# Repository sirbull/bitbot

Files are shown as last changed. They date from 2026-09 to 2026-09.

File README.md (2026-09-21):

# BitBot

**A tiny robot face with a voice, a camera, and a big personality.**

BitBot is a DIY AI companion built around the Seeed Studio XIAO ESP32-S3 Sense. It listens for a wake phrase or a button press, shows expressions and captions on a 240 × 240 screen, and can take a photo when asked what it sees. Its voice pipeline sends replies to a small speaker. The ESP32-S3 handles the hardware and local wake detection; conversations run through XiaoZhi over Wi-Fi.

> **Prototype status:** The display, face, camera, setup portal, wake phrases, and XiaoZhi conversation path have been implemented and tested in stages. Audible output from the physical speaker and the battery power system still need final bench verification. Battery life has not been measured.

## Meet the hardware

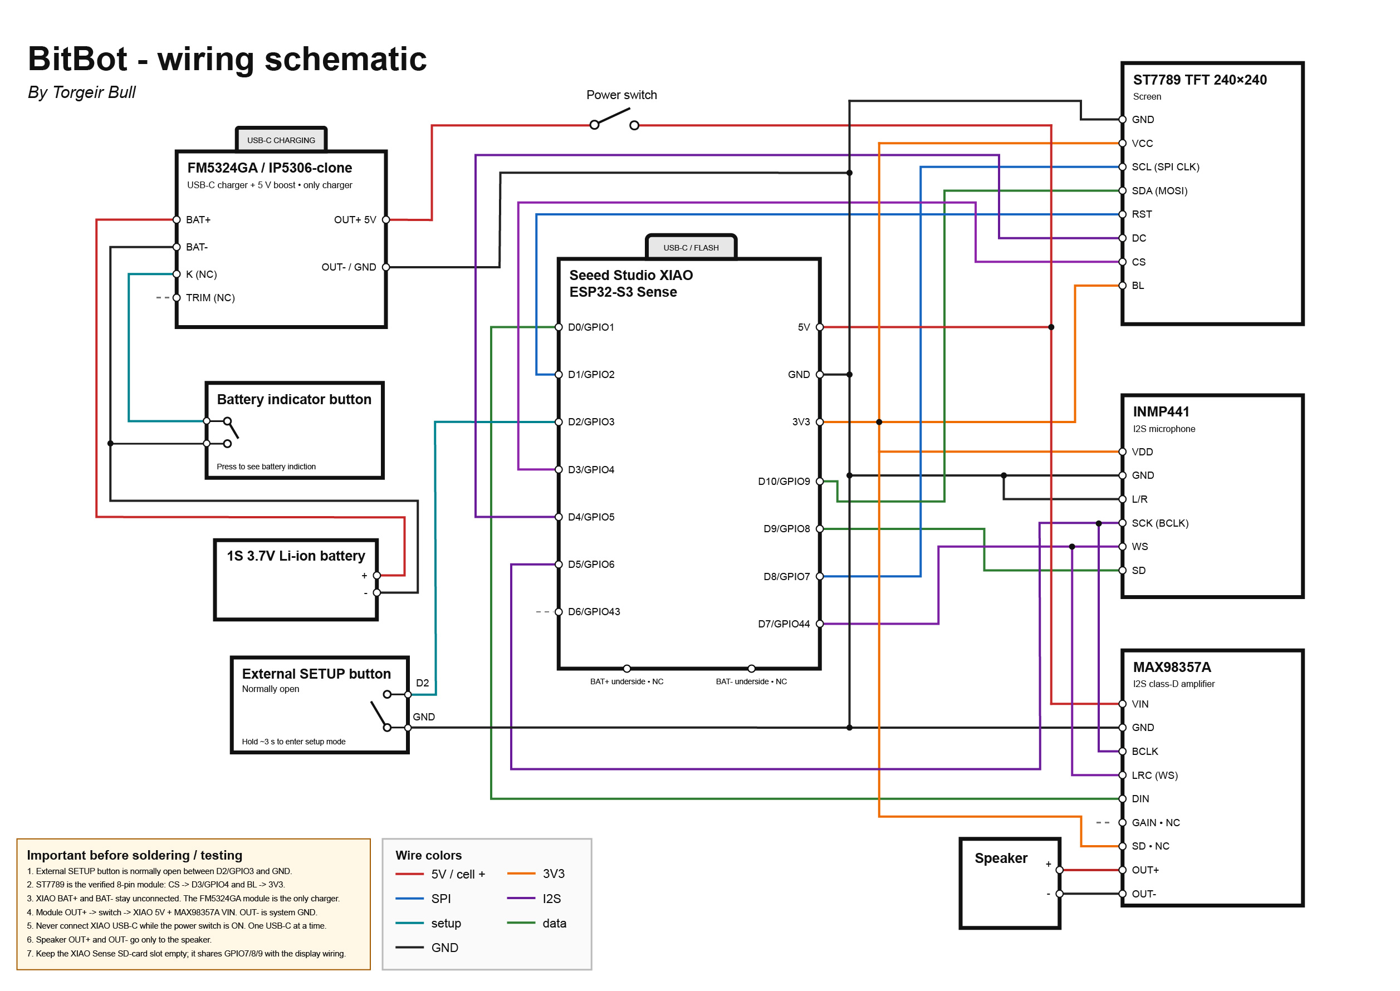
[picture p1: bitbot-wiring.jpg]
BitBot circuit wiring schematic


[Open the full-size circuit diagram](bitbot-wiring.jpg) · [Read the latest wiring notes](docs/wiring.md)

The image shows how the controller, screen, microphone, amplifier, speaker, controls, and power module fit together. It is a **prototype schematic**, so check the wiring notes before building: for example, the current notes connect the amplifier's `SD` pin to 3V3, while the image labels it `NC`.

### Parts at a glance

| Part | What it does |
| --- | --- |
| **Seeed Studio XIAO ESP32-S3 Sense** | Runs BitBot; includes Wi-Fi and the camera. |
| **1.54-inch ST7789 display, 240 × 240, 8-pin** | Shows the animated face, setup instructions, photos, and captions. |
| **INMP441 I²S microphone** | Captures speech. |
| **MAX98357A I²S amplifier + small speaker** | Plays BitBot's replies. |
| **Momentary button** (optional) | Starts a conversation or reopens setup; the onboard BOOT button also works. |
| **1S Li-ion cell, charger/5 V boost module, and latching switch** | Planned portable power; validate the cell and charging current before connecting them. |

See the [full component list](docs/components.md) for module details and the [hardware notes](docs/hardware.md) for electrical constraints. The Sense board's SD card slot stays empty because its pins are shared with the display.

## How BitBot works

1. **Set it up.** On first boot, BitBot opens its own Wi-Fi hotspot. Join it and open `http://192.168.4.1` to save a 2.4 GHz network and preferences. The screen shows setup information.
2. **Get its attention.** Press BOOT or the optional external button, or say **“hey robot”** or **“hey bit robot”**. Wake detection runs on the ESP32-S3. A custom “hey BitBot” wake model is future work.
3. **Have a conversation.** The microphone audio travels to XiaoZhi over Wi-Fi. BitBot receives the reply as text and audio, shows captions and a matching expression, and sends the audio to its speaker.
4. **Ask what it sees.** When the assistant requests a photo, BitBot captures one with the Sense camera, previews it on the display, and sends it to the vision service. The camera is not used continuously for conversation.

The face has twelve expressions, blinking eyes, and a dimmed idle view. Press the button again to interrupt or end a reply. [Learn more about the architecture](docs/architecture.md).

## What works today

| Area | Status |
| --- | --- |
| Screen, expressions, and captions | Implemented; ST7789 wiring verified on hardware. |
| Wi-Fi setup | Local English portal, saved network profiles, and a desktop simulator. |
| Voice and vision | XiaoZhi pairing and conversation flow, local wake phrases, and on-demand camera capture are implemented. Physical speaker output is still being diagnosed. |
| Portable power | Circuit planned; charging current, boost behavior, and battery runtime still need measurement. |

BitBot is a hands-on prototype, not a finished product. The [next-steps checklist](docs/next-steps.md) tracks the remaining physical tests.

## Try the setup portal on your computer

The simulator lets you explore BitBot's settings without hardware or an AI account. Install **Node.js 22 or later**, then run:

```sh
npm ci
npm run dev
```

Open **http://127.0.0.1:4173**. The simulator stores preferences in ignored `.local/simulator.json`; use dummy credentials. Its Wi-Fi checks are simulated and it makes no AI calls. To exercise a failed network test, enter `wrong-password`; other valid demo passwords simulate success.

## Build and flash the device

The firmware targets **ESP-IDF 6.0.2** and the original **XIAO ESP32-S3 Sense**. In an ESP-IDF shell:

```sh
cd firmware
idf.py set-target esp32s3
idf.py build
idf.py -p COM5 flash monitor
```

Replace `COM5` with your board's serial port. If you do not have ESP-IDF locally, see the [CI artifact flashing guide](docs/flashing.md). On first boot, join the `BitBot-XXXX` hotspot and open **http://192.168.4.1**. Holding BOOT for three seconds after startup reopens setup without erasing saved settings.

**Start on USB power with the battery module disconnected.** Read the [wiring guide](docs/wiring.md) before connecting external power. The XIAO's USB-C port and the boost module's switched 5 V output must not power the board at the same time.

## For contributors

Run the portal build and automated checks with:

```sh
npm ci
npx playwright install chromium
npm run check
```

The build generates compressed portal assets in `firmware/main/generated/`; commit those assets when changing `web/` or the settings schema. GitHub Actions also compiles the ESP32-S3 firmware.

| Path | Contents |
| --- | --- |
| [`firmware/`](firmware/) | ESP-IDF firmware for setup, face, audio, camera, and network. |
| [`web/`](web/) | Local setup portal shared by the device and simulator. |
| [`hwtest/`](hwtest/) | Separate hardware bring-up firmware. |
| [`docs/`](docs/) | Wiring, components, architecture, flashing, and progress notes. |
| [`BitBot_PROJECT_SPEC.md`](BitBot_PROJECT_SPEC.md) | Original project vision and requirements. |

This developer firmware stores credentials in NVS without flash encryption. Use test credentials while developing, and do not commit passwords or API keys.

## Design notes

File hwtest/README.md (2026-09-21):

# Maskinvaretest

Eget lite ESP-IDF-program som viser på skjermen hvilke deler som svarer.
Pinner som i [docs/wiring.md](../docs/wiring.md). Bruker samme partisjonstabell
som hovedfirmwaren, så lagrede Wi-Fi-innstillinger blir liggende.

```sh
. ~/esp/esp-idf-v6.0.2/export.sh
cd hwtest
idf.py -p /dev/cu.usbmodem11201 flash monitor
```

Tilbake til vanlig firmware: `cd ../firmware && idf.py -p ... flash`.

**D6/GPIO43 takler ikke en rask I2S-klokke** på dette kortet. BCLK flyttet
til D5/GPIO6 (var ledig siden batterisensing er fjernet). D6 fungerer fint
som sakte digital I/O (testet: 1 Hz toggling, ren 0/3,3V) — ledig pinne til
noe som en reset-linje, bare ikke en ny rask klokke.

| Linje | Grønn betyr | Rød / annet |
| --- | --- | --- |
| CPU / PSRAM | 8 MB PSRAM funnet | 0 MB: feil kort eller sdkconfig |
| MIC | INMP441 sender data; stolpen følger lyd | NO SIGNAL: SD-linjen (GPIO8) står fast. Sjekk VDD, SCK, WS, SD og L/R→GND. `MIC R` = L/R står høy |
| SPEAKER | `ok` og et lite tall: DMA-en ble aldri tom | BOOT stepper tonen: av, 2 %, 10 %, 40 %, 40 % uten mikrofon. Rød `GAP<ms>` betyr at skriveren ble sultet, og det hullet *er* skrapet |
| CAMERA | Sensornavn og bilder/s, bilde nederst | NOT FOUND: kamera-kabel. Trykk RESET etter tilkobling |

Trykker du BOOT innen 3 sekunder etter reset, starter i stedet en ren lyddiagnose:
skjerm, kamera, batteri og mikrofon blir aldri initialisert, og programmet veksler
mellom fire sekunder digital stillhet og fire sekunder 440 Hz. Støy under stillheten
kan ikke komme fra samplene. Videre BOOT-trykk stepper gjennom seks I2S-formater.

Uten kamera viser nederste halvdel tre felt som skal være rød, grønn, blå.
Kalibrering (invertering, radforskyvning) står øverst i
[main/main.cpp](main/main.cpp).

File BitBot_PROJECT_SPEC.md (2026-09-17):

# BitBot -- Project Specification for Codex

> **Purpose of this document:** This file is the persistent project
> brief for Codex and other development tools working on BitBot. Read it
> before making architectural, firmware, hardware, GPIO, display, audio,
> camera, networking, AI-provider, or power-management changes.

## 1. Project vision

BitBot is a small, portable, battery-powered AI assistant built around
the **Seeed Studio XIAO ESP32-S3 Sense**.

It is not a motorized robot. It has no wheels, servos, or locomotion.
The goal is to create a compact character-like AI device with:

-   voice interaction;
-   a reactive animated face;
-   a small color display;
-   a camera that is activated only when useful;
-   cloud-based AI over Wi-Fi;
-   Norwegian and English conversation;
-   spoken responses and simultaneous on-screen captions;
-   local device functions such as time, battery status, and camera
    preview;
-   aggressive but practical power management for portable battery
    operation.

The device should feel like a small character rather than merely a voice
terminal.

Two open-source projects should be investigated as important references:

-   `idevloop/AI_Pin-Wearable_Voice_Assistant_XIAO_ESP32S3_Sense`
-   `78/xiaozhi-esp32`

The first is especially relevant because it targets XIAO ESP32-S3 Sense
with camera and voice-assistant functionality. XiaoZhi is relevant as
the broader AI-assistant framework. BitBot may combine concepts or code
from both where licenses and architecture permit.

Do not assume that either project should simply be copied unchanged.
First determine which should be the primary technical foundation.

------------------------------------------------------------------------

## 2. Core hardware

### Main controller

**Seeed Studio XIAO ESP32-S3 Sense**

Requirements:

-   ESP32-S3 is the main MCU.
-   The Sense camera expansion board/camera must remain supported.
-   PSRAM should be used where appropriate.
-   Wi-Fi is required.
-   USB should remain usable for development/flashing/debugging.
-   GPIO assignments must be verified against official Seeed
    documentation and the actual camera pin usage.

### Camera

Use the camera supplied with the **XIAO ESP32-S3 Sense**.

The camera is **not intended to run continuously**.

Primary camera use cases:

1.  User asks a visual question such as:
    -   "What do you see?"
    -   "Hva ser du?"
    -   "What is this?"
    -   "Hva er dette?"
    -   "Read this."
    -   "Les dette."
2.  User requests a camera preview:
    -   "Show me what you see."
    -   "Vis meg hva du ser."
3.  While BitBot is awake, lightweight local person/face-position
    detection may optionally be used to make the on-screen eyes look
    toward the user.

The implementation must distinguish between:

-   local camera preview;
-   lightweight local visual tracking;
-   cloud vision inference.

Do not send camera images to a cloud service unless the requested
function actually requires cloud vision.

Camera operation should be designed with privacy, memory use, latency,
and battery consumption in mind.

### Display

**1.54-inch ST7789 TFT LCD**

Known characteristics:

-   240 × 240 pixels
-   SPI
-   7-pin style module
-   module pins:
    -   GND
    -   VCC
    -   SCL / SCK
    -   SDA / MOSI
    -   RES / RST
    -   DC
    -   BLK / BL

Owner-confirmed on 2026-09-10: with the pins at the top, the left-to-right
order is **GND, VCC, SCK, SDA, RES, DC, BLK**. This module has **no CS pin**.
Use ST7789 SPI support with chip-select disabled and exclusive bus ownership.
Do not use an SD card on that SPI bus. See `docs/hardware.md` for the current
signal allocation and unverified supply/backlight requirements.

Important:

-   This is **not** the SSD1306 OLED used by some reference projects.
-   BitBot must use the ST7789 as its main UI.
-   Verify the exact module electrical requirements before finalizing
    wiring.
-   Do not infer GPIO assignments from unrelated ESP32 boards.

### Microphone

**INMP441 digital MEMS microphone**

Interface:

-   I2S
-   pins typically include:
    -   VDD
    -   GND
    -   SCK / BCLK
    -   WS / LRCLK
    -   SD
    -   L/R

The microphone is used for:

-   local wake-word detection;
-   capturing user speech after wake-up;
-   sending speech/audio to the selected speech-recognition system where
    required.

Verify the actual module pinout before wiring.

### Audio amplifier

**MAX98357A I2S Class-D amplifier module**

Used for speech/audio output.

Expected signals include:

-   power;
-   GND;
-   I2S BCLK;
-   I2S LRCLK/LRC;
-   I2S DIN;
-   speaker outputs.

The amplifier may be disabled or power-managed when BitBot is inactive
if the hardware permits it.

### Speaker

Small rectangular speaker, approximately:

-   15 × 11 × 3.5--4 mm.

Verify actual impedance and power rating before finalizing amplifier
configuration.

Important: the MAX98357A speaker output is differential/bridge output.
Do not assume either speaker terminal connects to system ground.

### Battery

Current planned cell:

**10440 Li-ion** - nominal voltage: 3.7 V - advertised capacity:
approximately 350 mAh

The device must be portable and battery powered.

Battery runtime is an important design constraint. Measure real-world
current consumption once the prototype works.

### Charging / power module

Identified 2026-09-17. The purchased module is a **Type-C USB boost
converter, 5 V 2 A step-up with 1S Li-ion charging/protection and a
4-LED gauge**, built on an IC marked **FM5324GA**, a clone of the
**IP5306**.

Pads:

-   USB-C input (BitBot's charging port);
-   battery positive / battery negative;
-   5 V output positive / output negative;
-   external key pad `K`, marked as not connectable on this board;
-   charge-voltage trim point.

Topology is boost, not load-sharing: the 5 V rail is generated from the
cell while the cell charges from USB-C, so charging while BitBot is
switched off works. `BAT-` and `OUT-` are the same node, giving the
system one common ground.

The 5 V output becomes BitBot's supply rail: through the latching switch
to the XIAO's 5V pad and to the MAX98357A's VIN. **The module is the
only charger.** The XIAO's own `BAT+`/`BAT-` pads stay unconnected, and
the XIAO's USB-C must not be plugged in while the switch is on.

Two module characteristics remain to be measured on the bench, and both
can change component choices:

-   **actual charge current into a cell.** The family's default is close
    to 2 A, which is roughly 6C for a 350 mAh 10440 and unsafe. A larger
    cell or a current-limited charger may be required.
-   **boost auto-shutdown at low load.** The family cuts its output below
    roughly 45--100 mA. With no usable key pad, this may rule out deep
    sleep.

See `docs/hardware.md` for the test procedure and `docs/wiring.md` for
the wiring.

### Main power switch

A self-locking ON/OFF pushbutton has been purchased.

Approximate listing specification:

-   12 × 8 mm
-   latching/self-locking
-   advertised up to 30 V / 1 A

Only one switch will be used.

Prefer an arrangement that allows the battery to charge while BitBot is
switched off, if supported safely by the charging module.

### Battery measurement

BitBot should measure its own battery voltage.

Initial planned implementation:

-   2 × 100 kΩ, 1% resistors;
-   voltage divider from raw battery voltage to a suitable ESP32-S3 ADC
    input;
-   optional \~100 nF capacitor from ADC measurement node to GND for
    filtering.

Concept:

``` text
BAT+
 |
100k
 |
 +---- ADC
 |
100k
 |
GND
```

Software should compensate for the divider ratio and convert voltage to
an approximate Li-ion state of charge.

Do **not** use a simple linear 3.0--4.2 V percentage mapping if a more
realistic Li-ion lookup/curve can be implemented.

The result remains an estimate; load-dependent voltage sag should be
considered.

------------------------------------------------------------------------

## 3. No motors

BitBot does **not** require:

-   DC motors;
-   motor drivers;
-   wheels;
-   servos;
-   locomotion.

Do not reserve GPIO pins or power budget for motors unless the project
requirements are explicitly changed later.

------------------------------------------------------------------------

## 4. Wake word

BitBot should support a local wake phrase, initially:

**"Hey BitBot"**

Desired behavior:

``` text
low-power/idle
      |
"Hey BitBot"
      |
      v
   awake
      |
   listening
      |
 speech/command
```

Wake-word recognition should preferably happen locally on the ESP32-S3
rather than continuously streaming microphone audio to the cloud.

Goals:

-   lower network usage;
-   improved privacy;
-   lower cloud cost;
-   reduced unnecessary processing;
-   reasonable battery consumption.

Investigate practical ESP32-S3 wake-word solutions compatible with the
selected framework and with Norwegian/English usage.

Do not assume that deep sleep is compatible with microphone wake-word
recognition. Determine the lowest practical power state in which the
selected wake-word engine can function.

If true wake-on-voice from a very low-power state requires additional
hardware, document that clearly.

------------------------------------------------------------------------

## 5. Interaction state machine

BitBot should have explicit behavioral states rather than scattered UI
flags.

Initial conceptual states:

``` text
BOOTING
IDLE
SLEEPING / LOW_POWER
WAKING
LISTENING
PROCESSING
THINKING
SPEAKING
CAMERA_PREVIEW
VISION_PROCESSING
OFFLINE
ERROR
LOW_BATTERY
```

State transitions should drive:

-   face animation;
-   display content;
-   camera state;
-   microphone state;
-   amplifier/audio state;
-   Wi-Fi/network activity where practical;
-   backlight behavior;
-   power-management decisions.

Keep the state machine modular and understandable.

------------------------------------------------------------------------

## 6. Reactive face and character UI

The 240 × 240 ST7789 display should normally show a **BitBot face**.

The face is a major feature of the project.

It must be easy to redesign later without rewriting the AI/audio/camera
subsystems.

Prefer a dedicated abstraction such as:

``` cpp
face.setState(FaceState::Listening);
face.setGaze(x, y);
face.setSpeechLevel(level);
face.setCaption(text);
```

The exact API may differ, but UI/face rendering should be decoupled from
AI logic.

### Desired visual behavior

Possible expressions/states include:

-   sleeping;
-   waking;
-   neutral/idle;
-   listening;
-   thinking;
-   speaking;
-   happy;
-   amused;
-   uncertain;
-   confused;
-   surprised;
-   error;
-   low battery;
-   no Wi-Fi.

The face should not necessarily be implemented as a collection of static
full-screen bitmaps.

Where feasible, draw/animate individual components such as:

-   eyes;
-   pupils;
-   eyelids;
-   mouth;
-   eyebrows or equivalent expressive elements.

This makes redesign and animation easier.

### Idle animation

The face may:

-   blink occasionally;
-   make subtle eye movements;
-   react when woken;
-   transition smoothly between important states.

Avoid excessive animation that wastes CPU/battery without improving the
experience.

------------------------------------------------------------------------

## 7. Gaze / user position

When BitBot is awake and camera use is appropriate, the eyes should
optionally react to where a person appears in the camera image.

Example:

-   person appears left of image center -\> pupils move left;
-   person appears right -\> pupils move right;
-   person is higher/lower -\> gaze can shift vertically.

This should preferably use lightweight **local** detection rather than
repeatedly uploading images to a cloud vision model.

Important conflict to handle:

BitBot's camera should not run continuously while the device is asleep.
Therefore gaze tracking is expected primarily while BitBot is in an
awake/interactive state.

A possible policy is:

1.  BitBot is idle in a low-power state.
2.  "Hey BitBot" wakes it.
3.  During the active session, camera-based lightweight tracking may run
    when useful.
4.  After an inactivity timeout, tracking and camera are disabled.
5.  BitBot returns to low-power mode.

Investigate whether continuous camera operation during the entire awake
session is necessary. Prefer intermittent or low-frame-rate tracking if
it substantially improves battery life.

------------------------------------------------------------------------

## 8. Camera preview

The user should be able to say something equivalent to:

**"Vis meg hva du ser."**\
**"Show me what you see."**

BitBot should then show the camera image on the ST7789.

This is a local preview operation and should not require cloud AI.

Requirements:

-   camera initializes/activates;
-   frames are converted/scaled as required for 240 × 240;
-   image is shown on the ST7789;
-   provide a way to exit preview;
-   automatically exit after a sensible timeout if appropriate;
-   release/disable camera resources afterwards where practical.

Memory bandwidth, PSRAM, display SPI speed, frame format, and frame rate
should be considered.

A smooth 30 FPS video feed is not required. Responsiveness and
reasonable battery use are more important.

------------------------------------------------------------------------

## 9. Vision AI

When the user asks a question that genuinely requires visual
understanding, BitBot may:

1.  activate the camera;
2.  capture an appropriate still image;
3.  optionally resize/compress it;
4.  send it over Wi-Fi to a vision-capable AI service;
5.  receive the answer;
6.  speak and display the answer;
7.  deactivate the camera when no longer needed.

Examples:

-   "Hva ser du?"
-   "What is in front of you?"
-   "Hva slags plante er dette?"
-   "Les teksten på denne boksen."
-   "What color is this object?"

Cloud vision should be invoked by intent/tool selection, not
continuously.

------------------------------------------------------------------------

## 10. Languages

BitBot must support:

-   **Norwegian**
-   **English**

Norwegian is a first-class requirement, not an afterthought.

Desired behavior:

-   user can naturally speak Norwegian;
-   user can naturally speak English;
-   BitBot detects or infers the language;
-   BitBot normally answers in the same language;
-   no manual language switch should be required for ordinary
    conversation.

Evaluate Norwegian quality separately for:

-   speech-to-text (STT/ASR);
-   LLM;
-   text-to-speech (TTS);
-   wake-word recognition if relevant.

A provider that has an excellent English demo but poor Norwegian speech
is not an acceptable default.

------------------------------------------------------------------------

## 11. AI architecture

A large language model should **not run locally on the ESP32-S3**.

The ESP32-S3 is responsible primarily for:

-   device state;
-   wake word;
-   audio capture/playback;
-   camera capture;
-   local camera preview;
-   lightweight local visual tracking where feasible;
-   display/face;
-   captions;
-   battery monitoring;
-   Wi-Fi;
-   communication with remote AI services;
-   local tools/functions.

Remote services may provide:

-   STT;
-   LLM reasoning/conversation;
-   TTS;
-   vision.

### Cost target

Prefer:

1.  free tier where practical;
2.  very inexpensive usage-based services;
3.  services that do not require expensive monthly subscriptions.

However, reliability and Norwegian language quality matter.

Do not hard-code BitBot permanently to a single AI vendor if a provider
abstraction can reasonably be implemented.

Desired conceptual architecture:

``` text
Audio input
    |
    v
STT provider
    |
    v
Conversation / tool layer
    |
    +----> local tools
    |
    +----> LLM provider
    |
    +----> vision provider when required
    |
    v
response text
    |
    +----> captions
    |
    v
TTS provider
    |
    v
speaker
```

Investigate what XiaoZhi already provides before creating redundant
infrastructure.

------------------------------------------------------------------------

## 12. Local tools

Not every question should invoke a remote LLM.

BitBot should expose local device functions/tools where sensible.

Examples:

### Time

Questions such as:

-   "Hva er klokka?"
-   "What time is it?"

should use locally maintained/network-synchronized time rather than
requiring an LLM to invent or retrieve the time.

Use NTP after Wi-Fi connection and maintain time locally.

### Date

Same principle for date/day.

### Battery

Examples:

-   "Hvor mye batteri har du igjen?"
-   "What's your battery level?"

should query the ADC battery subsystem.

### Camera preview

"Vis meg hva du ser" should invoke the local camera-preview function.

### Device status

Potential future local tools:

-   Wi-Fi signal;
-   IP/network status;
-   uptime;
-   firmware version;
-   charging state, if hardware exposes it.

If XiaoZhi's MCP/tool system is suitable, investigate using it for these
functions.

------------------------------------------------------------------------

## 13. Speech output and captions

When BitBot speaks, the **same response should also be readable on the
display**.

The user should not have to wait until speech finishes before seeing the
text.

Desired behavior:

-   response text appears progressively or in useful chunks;
-   TTS playback occurs at the same time;
-   face remains visible as much as possible;
-   captions are readable on a 240 × 240 screen;
-   long text scrolls/pages/wraps intelligently.

The spoken response and displayed caption should originate from the same
canonical response text so they do not disagree.

The UI design may reserve a caption area or temporarily overlay captions
while speaking.

Support Norwegian characters correctly:

**æ ø å Æ Ø Å**

UTF-8/font support must be considered.

------------------------------------------------------------------------

## 14. Speech-reactive animation

The face should react while BitBot speaks.

At minimum, mouth animation can be driven by:

-   outgoing audio amplitude/RMS;
-   TTS playback buffer level.

If the chosen TTS service provides reliable phoneme/viseme timing, a
more advanced implementation may be considered later.

Do not make viseme support a hard dependency for the first working
version.

The goal is that the character visually appears to speak rather than
displaying a static face while audio plays.

------------------------------------------------------------------------

## 15. Wi-Fi

BitBot uses Wi-Fi to reach remote services and retrieve network data.

Requirements:

-   initial Wi-Fi provisioning must be practical;
-   reconnect automatically to known networks;
-   gracefully handle unavailable Wi-Fi;
-   show an understandable offline state;
-   avoid repeatedly hammering connection attempts if offline;
-   protect credentials appropriately;
-   make future reconfiguration possible.

Investigate whether XiaoZhi already provides suitable provisioning and
connection management.

------------------------------------------------------------------------

## 16. Power management

Power consumption is a major design constraint because BitBot is
portable.

Do not optimize prematurely at the expense of getting a working
prototype, but design the architecture so components can be
power-managed.

Investigate:

-   ESP32-S3 light sleep;
-   modem/Wi-Fi power saving;
-   wake-word requirements;
-   display backlight dimming/off;
-   camera deinitialization;
-   camera sensor power behavior;
-   MAX98357A shutdown behavior;
-   microphone/wake-word requirements;
-   CPU frequency/dynamic power management;
-   inactivity timeout.

A likely interaction model:

``` text
POWER ON
   |
   v
BOOT
   |
   v
IDLE / LOW POWER
   |
"Hey BitBot"
   |
   v
ACTIVE SESSION
   |
   +--> listen
   +--> think
   +--> speak
   +--> camera/vision if required
   +--> gaze tracking if enabled
   |
inactivity timeout
   |
   v
IDLE / LOW POWER
```

Do not claim a specific battery runtime until measured on real hardware.

------------------------------------------------------------------------

## 17. Privacy behavior

The design should make camera/microphone behavior understandable.

Principles:

-   wake-word processing should preferably be local;
-   ordinary idle audio should not continuously stream to cloud
    services;
-   camera should not continuously upload;
-   cloud vision should be activated only for relevant requests;
-   camera should normally be inactive while BitBot is sleeping;
-   document when audio/images leave the device.

A future UI indicator for cloud/camera activity may be useful.

------------------------------------------------------------------------

## 18. Software architecture goals

Prefer modular components with clear responsibilities.

Potential modules/classes/subsystems:

``` text
Application / StateMachine
WakeWord
AudioInput
SpeechRecognitionProvider
ConversationManager
LlmProvider
VisionProvider
TtsProvider
AudioOutput
CameraManager
PersonTracker
DisplayManager
FaceRenderer
CaptionRenderer
BatteryMonitor
WifiManager
TimeService
ToolRegistry / MCP
PowerManager
Settings / Provisioning
```

Names are illustrative, not mandatory.

Avoid a monolithic main loop containing all behavior.

Use asynchronous/event-driven behavior where appropriate, while
respecting ESP32 memory constraints.

------------------------------------------------------------------------

## 19. Face redesignability

A future developer/designer should be able to change BitBot's appearance
without understanding the AI networking stack.

Separate:

**behavior/state**

from

**visual representation**.

For example, application logic should communicate:

``` text
expression = LISTENING
gazeX = -0.4
gazeY = 0.1
speechLevel = 0.65
caption = "Ja, selvfølgelig."
```

The renderer decides how that looks.

Consider a configurable face geometry/theme system if practical.

Potential future themes:

-   minimal;
-   cute;
-   retro computer;
-   robotic;
-   custom BitBot identity.

Do not imitate copyrighted character artwork directly.

------------------------------------------------------------------------

## 20. Development approach

Do **not** attempt to implement the entire project in one pass.

Recommended phases:

### Phase 0 -- Research and architecture

Before writing major firmware:

1.  Inspect `78/xiaozhi-esp32`.
2.  Inspect
    `idevloop/AI_Pin-Wearable_Voice_Assistant_XIAO_ESP32S3_Sense`.
3.  Check their current licenses.
4.  Determine which should be the primary base.
5.  Read official Seeed XIAO ESP32-S3 Sense documentation.
6.  Verify camera GPIO usage.
7.  Verify available GPIOs.
8.  Verify ST7789 electrical/interface requirements.
9.  Verify INMP441 requirements.
10. Verify MAX98357A requirements.
11. Identify I2S/SPI/GPIO conflicts.
12. Evaluate RAM/PSRAM/flash requirements.
13. Investigate Norwegian-capable STT/TTS/LLM/vision providers.
14. Investigate wake-word options.
15. Document risks.
16. Produce an architecture proposal.

Do not make major implementation changes until this analysis is
complete.

### Phase 1 -- Basic hardware bring-up

Goal:

-   XIAO boots reliably;
-   serial logging;
-   ST7789 works;
-   test UI/face;
-   INMP441 captures audio;
-   MAX98357A plays test audio;
-   camera captures an image;
-   battery ADC works;
-   Wi-Fi connects.

Test each subsystem independently before integrating AI.

### Phase 2 -- UI and state machine

Implement:

-   states;
-   face rendering;
-   blink/idle;
-   listening animation;
-   thinking animation;
-   speaking animation;
-   captions;
-   battery indicator;
-   Wi-Fi indicator where appropriate.

### Phase 3 -- Voice assistant

Implement:

-   wake word;
-   audio capture;
-   STT;
-   LLM;
-   TTS;
-   synchronized captions;
-   Norwegian and English.

### Phase 4 -- Camera / vision

Implement:

-   camera preview;
-   vision intent/tool;
-   cloud vision requests;
-   camera lifecycle management.

### Phase 5 -- Gaze tracking

Investigate and implement lightweight local person/face-position
detection if feasible.

The feature must not destabilize core voice functionality.

### Phase 6 -- Power optimization

Measure current in each state and optimize based on evidence.

------------------------------------------------------------------------

## 21. Hardware verification rules for Codex

These rules are mandatory.

### Never invent GPIO assignments

Before assigning a GPIO:

1.  verify the official XIAO ESP32-S3 Sense pin map;
2.  verify camera/expansion-board pin usage;
3.  check boot/strapping restrictions;
4.  check peripheral conflicts;
5.  check whether the reference firmware already reserves the pin.

Record the final allocation in a hardware document/table.

### Never guess power-module behavior

The exact USB-C battery/boost module must be identified or electrically
verified before final power wiring is approved.

### Do not copy pin numbers from generic ESP32 examples

The XIAO ESP32-S3 Sense has its own pin mapping and camera
configuration.

### Datasheets first

Prefer:

1.  manufacturer datasheets;
2.  official Seeed documentation;
3.  official component documentation;
4.  source code from the selected upstream framework.

Treat random wiring diagrams/blog posts as secondary evidence.

------------------------------------------------------------------------

## 22. Breadboard / prototype documentation

Once GPIO allocation is verified, maintain a definitive wiring table.

Example structure:

  BitBot function   Module pin         XIAO pin   GPIO   Voltage       Notes
  ----------------- ------------------ ---------- ------ ------------- --------
  TFT clock         SCL/SCK            TBD        TBD    3.3 V logic   Verify
  TFT MOSI          SDA/MOSI           TBD        TBD    3.3 V logic   Verify
  TFT DC            DC                 TBD        TBD    3.3 V logic   
  Microphone BCLK   SCK                TBD        TBD    3.3 V         
  Microphone data   SD                 TBD        TBD    3.3 V         
  Amplifier data    DIN                TBD        TBD    3.3 V logic   
  Battery sense     divider midpoint   TBD        TBD    ADC-safe      

`TBD` must remain `TBD` until verified. Do not replace uncertainty with
guesses.

The wiring table should be treated as authoritative over generated
illustrations.

------------------------------------------------------------------------

## 23. AI/provider evaluation

Before choosing cloud providers, compare candidates for:

-   Norwegian STT quality;
-   English STT quality;
-   Norwegian TTS naturalness;
-   English TTS naturalness;
-   latency;
-   streaming support;
-   vision capability;
-   ESP32-friendly protocol/API;
-   free tier;
-   expected low-volume cost;
-   authentication complexity;
-   vendor lock-in;
-   privacy;
-   whether self-hosting is possible.

Prefer an architecture where providers can be replaced.

The cheapest service is not automatically the best choice if Norwegian
speech quality is poor.

------------------------------------------------------------------------

## 24. Error handling

BitBot should fail gracefully.

Examples:

### No Wi-Fi

Display an offline expression/status rather than hanging.

Local functions such as battery and potentially time should remain
available.

### AI service unavailable

Tell the user succinctly rather than silently failing.

### Camera failure

Return to the normal UI and report the error.

### Low battery

Show a low-battery state and avoid starting expensive operations if
voltage becomes unsafe.

### Audio failure

Log useful diagnostics over serial.

------------------------------------------------------------------------

## 25. Logging and debugging

During development, provide useful serial logging for:

-   state transitions;
-   Wi-Fi;
-   audio initialization;
-   camera initialization;
-   display initialization;
-   battery voltage;
-   wake-word events;
-   API request status;
-   memory/PSRAM availability;
-   recoverable errors.

Never log:

-   API secrets;
-   Wi-Fi passwords;
-   sensitive authentication tokens.

------------------------------------------------------------------------

## 26. Secrets

Do not commit real API keys or Wi-Fi credentials to Git.

Use the framework's appropriate secrets/configuration mechanism.

Provide example/template configuration files where useful.

------------------------------------------------------------------------

## 27. Definition of a successful first complete prototype

The first major BitBot milestone is achieved when the physical device
can:

1.  boot from battery;
2.  connect to Wi-Fi;
3.  show its animated face;
4.  display battery status;
5.  wait for "Hey BitBot";
6.  visibly react to the wake word;
7.  listen to a spoken Norwegian or English question;
8.  transcribe it correctly enough for conversation;
9.  obtain an AI response over Wi-Fi;
10. display the response as readable captions;
11. speak the same response through the speaker;
12. animate its face while speaking;
13. answer in the same language as the user;
14. show the camera view when asked;
15. use cloud vision when a question requires visual understanding;
16. stop/deactivate camera functionality when it is no longer needed;
17. return to a lower-power idle state after inactivity.

Gaze tracking is desirable but should not block the first complete
voice-assistant milestone.

------------------------------------------------------------------------

## 28. Instructions to Codex

When beginning work on this repository:

1.  Read this entire document.
2.  Inspect the existing repository before changing anything.
3.  Investigate the two upstream projects.
4.  Verify hardware facts against primary documentation.
5.  Do not invent missing specifications.
6.  Clearly distinguish verified facts from assumptions.
7.  Prefer extending proven upstream functionality over rewriting
    working systems.
8.  Keep BitBot-specific hardware/UI code isolated where practical.
9.  Preserve the ability to update/merge relevant upstream changes.
10. Optimize for maintainability, battery operation, and ESP32-S3
    resource limits.
11. Do not implement all phases at once.
12. Compile/test after meaningful changes whenever the toolchain is
    available.
13. Document unresolved hardware questions instead of guessing.
14. Keep Norwegian and English support as core requirements.
15. Keep camera activation intentional and power-aware.
16. Keep the face renderer replaceable/redesignable.
17. Keep captions synchronized with the canonical spoken response.
18. Keep cloud AI providers replaceable where reasonably possible.

### First task for Codex

Before implementing the complete firmware:

> Analyze the requirements in this document and inspect both upstream
> projects. Determine the best technical foundation for BitBot. Verify
> the XIAO ESP32-S3 Sense hardware and camera constraints using official
> documentation. Propose a GPIO/peripheral allocation, identify
> conflicts and technical risks, evaluate the software architecture and
> AI-provider options, and create an implementation plan. Do not
> implement the complete project yet. Present the findings before
> proceeding with major implementation.

------------------------------------------------------------------------

## 29. Reference repositories

-   AI Pin for XIAO ESP32-S3 Sense:\
    `https://github.com/idevloop/AI_Pin-Wearable_Voice_Assistant_XIAO_ESP32S3_Sense`

-   XiaoZhi ESP32:\
    `https://github.com/78/xiaozhi-esp32`

When using code from upstream projects, verify and respect the license
of the exact source being used.

------------------------------------------------------------------------

## 30. Current project name

**BitBot**

Wake phrase:

**"Hey BitBot"**

These may be changed later, so avoid unnecessarily hard-coding branding
throughout unrelated subsystems.

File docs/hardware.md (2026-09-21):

# Hardware review — no final external wiring yet

The default commissioning build enables only the onboard BOOT button,
GPIO0, input with pull-up. RESET is CHIP_PU; native USB uses GPIO19/20.
The ST7789 driver is enabled by default since the display was verified on
hardware (2026-09-19).

**Verified on hardware, 2026-09-19:** the fitted module is an 8-pin ST7789,
240×240: **GND, VCC, SCL, SDA, RST, DC, CS, BL** (the 2026-09-10 note of a
7-pin module without CS was wrong). SCL/SDA here mean SPI clock/MOSI, not I2C. CS is on
D3/GPIO4; VCC and BL go to 3V3. The driver uses SPI mode 3. With CS floating
the panel stays dark, and with BL floating the backlight stays off. No SD card.

## Verified target facts

[Seeed getting started and pin tables](https://wiki.seeedstudio.com/xiao_esp32s3_getting_started/)
identify the original Sense board's 8 MB flash/8 MB PSRAM, GPIO0 BOOT,
GPIO21 user LED, and onboard PDM microphone (clock 42, data 41).
Camera allocation is fixed:

| Camera signal | GPIO |
| --- | --- |
| XCLK | 10 |
| SCCB SDA / SCL | 40 / 39 |
| D0, D1, D2, D3 | 15, 17, 18, 16 |
| D4, D5, D6, D7 | 14, 12, 11, 48 |
| VSYNC / HREF / PCLK | 38 / 47 / 13 |
| Sensor RESET / PWDN | Not exposed as separate GPIO in Seeed example |

The fitted sensor on this unit is an **OV3660** (identified on hardware
2026-09-19), not the OV2640 some revisions carry.

## Signal allocation, pending physical validation

[Seeed pin multiplexing](https://wiki.seeedstudio.com/xiao_esp32s3_pin_multiplexing/)
maps D0–D10 to 1,2,3,4,5,6,43,44,7,8,9. GPIO41/42 are not ADC inputs.
The Sense SD socket occupies 3/7/8/9. Keep it empty and disabled for this
prototype; do not share SPI with an active SD card. GPIO3 (also the empty SD slot's CS) takes an optional setup button to GND;
its strapping role only applies with the STRAP_JTAG_SEL eFuse burned. Do not cut microphone jumpers for this proposal.

| Function | Proposed pad / GPIO | Final wiring | Constraint |
| --- | --- | --- | --- |
| TFT SCL (SPI clock) | D8 / 7 | Driver allocation | Shared with unused SD clock |
| TFT SDA (MOSI) | D10 / 9 | Driver allocation | Shared with unused SD MOSI |
| TFT DC | D4 / 5 | Driver allocation | 3.3 V logic |
| TFT CS | D3 / 4 | Verified | |
| TFT RST | D1 / 2 | Driver allocation | Active-low reset; validate on module |
| TFT backlight (BL) | 3V3 | Verified | Always on; GPIO dimming would need a transistor |
| INMP441 + amplifier BCLK | D5 / 6 | Verified, moved | D6/GPIO43 cannot hold a fast I2S clock on this board (found by isolating I2S on a bare transmitter and swapping pins); moved to the pin freed by dropping battery sensing. D6/GPIO43 itself still works fine as slow GPIO (1 Hz toggle, clean 0/3.3V) - spare pin for something like a reset line, just not another fast clock |
| INMP441 + amplifier WS | D7 / 44 | TBD | Shared standard I2S frame clock; UART0 RX unavailable |
| INMP441 SD → ESP RX | D9 / 8 | TBD | SD card absent; 3.3 V mic supply |
| ESP TX → MAX98357A DIN | D0 / 1 | TBD | Separate from microphone data |
| Setup button | Onboard BOOT / 0 | Verified onboard | Hold 3 s for setup, short press to talk |
| External setup button | D2 / 3, to GND | Optional | Internal pull-up; hold 3 s after boot, like BOOT |

The original eight-signal assumption exhausted the non-strapping header pins.
With CS on GPIO4 and BL on 3V3, GPIO6 (D5) was unused and now carries BCLK
(moved off the faulty D6/GPIO43 - see the pin table above and
[wiring.md](wiring.md)). There is no battery voltage sensing. No
I/O expander, microphone jumper cut, or replacement microphone is assumed.
Microphone and speaker sharing BCLK/WS requires matching slot width and sample
rate; initially 16 kHz, stereo 32-bit slots, resampling TTS as necessary.
Independent 16 kHz receive/24 kHz transmit is incompatible with those shared
clocks. USB serial remains available on GPIO19/20.

## Electrical checks

- **ST7789:** ESP-IDF has an ST7789 SPI panel driver
  ([Espressif LCD documentation](https://docs.espressif.com/projects/esp-idf/en/stable/esp32s3/api-reference/peripherals/lcd/index.html)).
  Controller support does not verify the unknown module's regulator, backlight
  resistor, supply voltage, panel offset, or rotation. Obtain
  its exact product page/schematic before power wiring; all ESP signals are
  3.3 V logic. Do not drive an unknown backlight load directly from a GPIO.
- **INMP441:** [TDK datasheet](https://invensense.tdk.com/wp-content/uploads/2015/02/INMP441.pdf)
  specifies 1.8–3.3 V operation and 24-bit standard I2S data. Wire L/R deliberately
  for the chosen slot; verify breakout pin labels, decoupling, and grounding.
- **MAX98357A:** [Analog Devices](https://www.analog.com/en/products/max98357a.html)
  specifies 2.5–5.5 V supply, standard I2S, no MCLK, and differential speaker
  outputs. Neither speaker terminal is ground. Verify actual speaker impedance,
  rating, gain strap, and SD/shutdown circuit. Do not infer module wiring from
  the IC's voltage range alone.
- **Battery:** not measured by BitBot. The module's 4-LED gauge is the only
  charge indicator. No runtime is established.
- **Charging / 5 V supply (identified 2026-09-17):** the purchased module is a
  Type-C USB boost converter with a 1S Li-ion charger, protection and a 4-LED
  gauge, built on an IC marked **FM5324GA** — an IP5306 clone. Datasheet
  behaviour for the family: 4.2 V CC/CV charge, up to ~2 A charge current,
  5 V boost output rated 2 A, over-charge/over-discharge/short protection, and
  a key input for on/off that this board marks unusable. Pads: USB-C in,
  BAT+, BAT−, 5V OUT+, OUT−, K, and a charge-voltage trim point. BAT− and OUT−
  are one node, so the whole system shares a ground. Topology is boost, not
  load-sharing: the 5 V rail is generated from the cell, and the cell charges
  from USB-C, which is what makes charge-while-off work. Wiring follows from
  that and is drawn in [wiring.md](wiring.md): module BAT pads own the cell,
  OUT+ through the latching switch to the XIAO 5V pad and the amp's VIN, the
  XIAO's own BAT+/BAT− pads left empty.
  Two things must be measured on the bench before the cell is trusted:
  - **Charge current versus cell size.** A 350 mAh 10440 at this family's
    default charge current is roughly 6C — far outside the cell's rating. Meter
    the actual current into a cell first. If it is above ~0.35 A, use a larger
    cell (a 1000 mAh+ 18650 or an 18650-class pouch puts the module in its
    intended range) or a charger whose current can be set. Do not "try it and
    watch". The trim point adjusts charge voltage, not current.
  - **Boost auto-shutdown threshold.** IP5306-family parts drop the 5 V output
    when the load falls below roughly 45–100 mA for about 32 s. BitBot awake
    with the display on should stay above that; BitBot in deep sleep will not.
    With no usable K pad, recovery then depends on the board's auto-load
    detection, which has to be confirmed by experiment. If it does not recover,
    aggressive sleep is off the table for this module and the power budget has
    to be built around a light-sleep floor instead.
  Do not plug the XIAO's USB-C in while the switch is on: its 5V pad is VBUS
  with no blocking diode. Begin bring-up on the XIAO's USB with the module
  disconnected.

## Bring-up sequence

1. USB boot, chip/PSRAM check, BOOT hold, Wi-Fi/portal and recovery tests.
2. Verify module identities and resolve pin conflict; publish final wiring table.
3. ST7789 solid colors, rotation, readable `æ ø å Æ Ø Å`, blink/face demo.
4. Test microphone capture and amplifier output separately at low volume.
5. Camera one-frame capture and release; no network upload.
6. Power module alone: charge current into a cell, termination, 5 V under load,
   and the output's behaviour at ~30 mA. Decide the cell from that result.
7. Verified power path, then combined load/current test.

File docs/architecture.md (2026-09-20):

# BitBot: first development milestone

Research date: 2026-09-08. Read alongside `BitBot_PROJECT_SPEC.md`.

## Decision

Use **XiaoZhi as the foundation for the voice assistant**, with a separate
BitBot board, face renderer, and commissioning/settings component. First build
and verify commissioning independently; do not boot unverified external GPIOs.
The repository's first runnable firmware is this commissioning application,
not the finished talking robot. The same English portal runs on the device and
in a clearly labelled desktop simulator. No external website, CDN, or account
is needed to load the portal.

### Upstream inspection

| Reference | Inspected revision | Finding |
| --- | --- | --- |
| [78/xiaozhi-esp32](https://github.com/78/xiaozhi-esp32/tree/c7241272f2d5fd140c77542f3cf12d09e717fc2f) | `c7241272f2d5fd140c77542f3cf12d09e717fc2f` | MIT; ESP-IDF 6.0.2 preferred by its README. Provides ESP-SR wake word, Opus/audio pipeline, MCP tools, display/camera abstractions, and configurable network transports. |
| [AI Pin](https://github.com/idevloop/AI_Pin-Wearable_Voice_Assistant_XIAO_ESP32S3_Sense/tree/a2f44493c40593d34b7f10bdf043655eb53d3881) | `a2f44493c40593d34b7f10bdf043655eb53d3881` | MIT derivative of XiaoZhi; mostly a board header and prebuilt binaries. PDM microphone and SSD1306 differ from BitBot. RGB GPIO19/20 conflict with native USB. Do not flash its binary onto BitBot's proposed wiring. |

Inspected XiaoZhi's `main/boards/common/wifi_board.cc`, board guide,
`main/idf_component.yml`, camera board implementation, and audio codec interface.
Its `78/esp-wifi-connect` 3.2.2 dependency already supports saved networks,
connection backoff, and captive provisioning. However, the inspected portal
opens an unsecured AP, provides no public custom-route/server hook, and uses
GET requests for some mutations. Its DNS response builder also needs packet
bounds checks before reuse. BitBot therefore implements a small independent
commissioning component on ESP-IDF's Wi-Fi/HTTP/NVS APIs, while retaining the
decision to reuse XiaoZhi's much larger voice pipeline. No upstream source or
prebuilt binary is copied into this milestone. Recheck licences and preserve
notices when importing code later.

## User journey

1. First boot opens a password-protected `BitBot-XXXX` hotspot. During this
   bring-up build the setup password is explicitly displayed on USB serial,
   not written to ordinary logs. The ST7789 must show it in the next milestone.
2. Join that hotspot, stay connected even if the phone says "no internet", and
   open `http://192.168.4.1`. A captive-portal redirect is a convenience; that
   numeric address is always the documented fallback.
3. Scan for 2.4 GHz Wi-Fi, select a network, enter its password, and test it.
   Only a successful association **and DHCP lease** stores/replaces the profile.
   This does not prove internet or AI-service access. Failed attempts preserve
   existing credentials and assistant settings. Up to five profiles are kept.
4. Adjust assistant preferences and save. Leave a key blank to keep it;
   removing a key is a separate explicit operation. Secrets never appear in
   settings responses.
5. Finish setup. The device restarts, closes the hotspot, and tries saved
   networks. If those are unavailable, it retries with a bounded delay.
6. At another location, hold **BOOT for three seconds after boot** to reopen
   setup. Nothing is erased. RESET only reboots. BOOT held during power-on
   enters the ROM downloader and cannot trigger application setup.

After initial commissioning, setup requires the physical button; loss of Wi-Fi
does not silently expose configuration. Setup closes after ten minutes and
returns to connection attempts. The first-boot portal stays available until
a network is configured. The latching power switch is not a settings button.
An accessible momentary button can be added later once its pin is verified.

## Architecture boundaries

```mermaid
flowchart LR
  Browser[English portal in ESP flash] --> API[Commissioning API]
  API --> Settings[Versioned NVS settings]
  API --> Wifi[Wi-Fi test and profile management]
  Button[BOOT long press] --> Wifi
  subgraph Later voice integration
    Wake[Local ESP-SR wake word] --> Audio[XiaoZhi audio pipeline]
    Audio --> Remote[Replaceable remote AI services]
    Remote --> Reply[Canonical response text]
    Reply --> Captions[UTF-8 captions]
    Reply --> TTS[Speech playback]
    TTS --> Face[Independent face renderer]
  end
```

Update 2026-09-20: the conversation path above is implemented. The microphone is
only captured after a wake phrase or a button press, and the camera only when
the assistant asks for a photo through MCP.

The commissioning build itself does not capture microphone/camera data or call an
AI provider. Independent conversation/speech providers, personality, voice, and
display preferences are stored for integration; saving them must not imply that
those integrations exist.
The simulator never joins networks or invokes a paid API.

## Security and storage

- Random per-device WPA2 setup password, generated on first boot and persisted.
  Never derive a password from the MAC. Treat it as a physical setup credential.
  **Current prototype override (2026-09-19):** the owner chose a fixed setup
  password, `BitBot2000`, in `network.cpp`. Revert before sharing devices.
- Local HTTP is restricted to the AP interface/subnet. No administration on the
  joined LAN. Require a per-session token header for API mutations; reject
  foreign origins and bound bodies. Do not enable CORS.
- NVS is not a vault by default. This developer firmware has **no flash/NVS
  encryption or secure boot**. Physical flash extraction can reveal credentials.
  Before sharing finished devices, provision encryption/secure boot deliberately;
  prefer scoped device tokens instead of high-value provider keys.
- Use one versioned NVS document with validated bounded settings and network
  profiles. Commit successful changes before updating RAM. Never automatically
  erase NVS on corruption or a version mismatch.
- No Wi-Fi passwords/API keys in Git, logs, status, exported public settings,
  or browser persistent storage. Desktop simulator persistence is under ignored
  `.local/`; use dummy credentials there.
- Later cloud clients must verify TLS certificates and time, limit responses,
  and support timeouts/cancellation. Do not weaken TLS to make a demo work.

## Memory, power, and remaining risks

Update 2026-09-10: the owner confirmed a seven-pin ST7789 with no CS. An optional
native `esp_lcd` bring-up driver now uses that interface; see `hardware.md` for
the exact pin list and remaining supply/backlight checks. It uses a 7,680-byte
DMA stripe buffer and waits for transfer completion before reuse. It is disabled
by default, so external wiring is not energized just by flashing commissioning.

The target is the original XIAO ESP32-S3 Sense (8 MB flash, 8 MB PSRAM), not a
Plus variant. Confirm the installed board and sensor. Commissioning keeps the
web assets compressed in flash and limits requests to 12 KiB. A 240×240 RGB565
frame alone uses 115,200 bytes; reserve PSRAM for camera frames/audio where
supported and keep DMA-capable buffers in suitable memory. Actual combined
heap/PSRAM measurements come before choosing full frame double-buffering.

[ESP-SR WakeNet](https://docs.espressif.com/projects/esp-sr/en/latest/esp32s3/wake_word_engine/README.html)
supports ESP32-S3, but changing a string does not create a trained "Hey BitBot"
detector. Start with push-to-talk or a supported model, then train/provision and
measure that exact phrase. Microphone inference needs a running audio/CPU path;
ordinary deep sleep cannot keep it running. Measure idle, listening, speaking,
Wi-Fi, and camera current before promising runtime from the 350 mAh cell.

School/enterprise Wi-Fi, hotel captive login pages, AP client isolation, and
5-GHz-only networks are not covered by WPA2 personal provisioning. A 2.4 GHz
phone hotspot is a practical demo network. A self-hosted AI service must also
be reachable from the new location; storing its address does not provide that
reachability.

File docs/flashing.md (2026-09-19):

# Laste opp firmware til ESP32-S3 fra Mac

Enkleste vei: GitHub Actions bygger firmware ved hver push. Last ned ferdig
build og flash den med `esptool`. Du trenger ikke installere ESP-IDF.

## Engangsoppsett

```sh
brew install esptool gh
gh auth login
```

## 1. Finn porten

Koble til med USB-C (en kabel som kan overføre data, ikke bare lade).

```sh
ls /dev/cu.usbmodem*
```

Du får noe som `/dev/cu.usbmodem11201`. Finner du ingen: hold **BOOT**, trykk
**RESET**, slipp **BOOT**, og prøv igjen.

## 2. Hent siste build fra CI

Sjekk at siste kjøring på `main` er grønn og at du har pushet det du vil teste:

```sh
cd bitbot
gh run list -L 3
rm -rf /tmp/bitbot-fw
gh run download -n bitbot-commissioning-esp32s3 -D /tmp/bitbot-fw
```

Uten run-ID laster `gh run download` ned fra siste kjøring. Vil du ha en
bestemt build, legg til ID-en: `gh run download <id> -n ...`.

## 3. Flash

```sh
cd /tmp/bitbot-fw
esptool --chip esp32s3 -p /dev/cu.usbmodem11201 -b 460800 write-flash @flash_args
```

Den skal avslutte med `Hash of data verified.` og `Hard resetting`.

**Ikke kjør `erase-flash`** ved vanlige oppdateringer. Det sletter lagrede
innstillinger (Wi-Fi, nøkler).

## 4. Se loggen og oppsettpassordet

```sh
screen /dev/cu.usbmodem11201 115200
```

Trykk **RESET** på kortet for å se oppstarten. Nederst står:

```
BITBOT PHYSICAL SETUP
Network: BitBot-XXXX
Setup password: ...
Open http://192.168.4.1
```

Avslutt `screen` med `Ctrl-A`, så `K`, så `y`.

Koble deg til `BitBot-XXXX` med passordet og åpne http://192.168.4.1.

## Feilsøking

| Problem | Løsning |
| --- | --- |
| `Failed to connect` / porten er opptatt | Lukk `screen` eller andre seriemonitorer, prøv igjen |
| Ingen `usbmodem`-port | Bytt kabel, eller BOOT + RESET for nedlastingsmodus |
| Sjekk hvilken brikke som er koblet til | `esptool -p /dev/cu.usbmodem11201 chip-id` (skal si ESP32-S3) |

## Bygge lokalt i stedet

Bare nødvendig hvis du vil teste endringer uten å pushe. Installer
[ESP-IDF 6.0.2](https://docs.espressif.com/projects/esp-idf/en/stable/esp32s3/get-started/),
og så:

```sh
cd firmware
idf.py set-target esp32s3
idf.py build
idf.py -p /dev/cu.usbmodem11201 flash monitor
```

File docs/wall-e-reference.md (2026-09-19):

# Additional reference: Huy Vector's Wall-E AI

Inspected after the owner supplied the links. These are observations from
publicly served files, not a recovered source tree or a licence to reuse its
character artwork/firmware.

- [Project page](https://www.huyvector.org/robots-kinetic/wall-e-ai) lists XIAO
  ESP32-S3 Sense with OV3660, a 1.54-inch display, amplifier and motors. A wiring
  diagram is linked, but its Google-hosted image returned HTTP 403 during this
  inspection. It has not been used as verified pin evidence.
- [Web installer](https://huyvector.github.io/wall-e-ai-installer/) uses
  `esp-web-tools@10`, browser USB/serial, and version 2.4.0. Its wording confirms
  that installation clears saved Wi-Fi. Browser installation and Wi-Fi setup
  are different operations.
- [Public manifest](https://huyvector.github.io/wall-e-ai-installer/manifest.json)
  targets `ESP32-S3`, flashes one factory image at offset 0, requests an erase
  prompt, and sets `improv: false`. It does not describe display pins.
- Read-only inspection of strings in the publicly downloadable factory image
  found `esp_lcd_new_panel_st7789`, `lcd_panel.st7789`, `xiaozhi`,
  `v5.5.2-dirty`, OV3660 driver names and `wn9_hiwalle_tts2`. These support the
  inference that it uses an ESP-IDF/XiaoZhi-based ST7789 build with a custom
  WakeNet model. Binary strings alone do not establish the source revision,
  complete GPIO map, schematic, licence compliance, or successful operation.

The [installer repository](https://github.com/huyvector/wall-e-ai-installer)
contains the site, images, manifest and binary. No firmware source or explicit
licence was present in the inspected file tree. Nothing from those files is
redistributed in BitBot. The useful architectural lessons are browser-assisted
firmware installation, ST7789 compatibility, and a real trained wake word.
BitBot has no motors and uses its own face design.

The owner subsequently confirmed the actual display as **ST7789 240×240** with
**GND, VCC, SCL, SDA, RST, DC, CS, BL** (verified on hardware 2026-09-19; an
earlier 7-pin, no-CS note was wrong). This pin list, together with Seeed's MCU
pin map and Espressif's LCD driver, is the basis of BitBot's display
implementation; the opaque factory binary is not.

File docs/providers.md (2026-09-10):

# Provider choices and language validation

Research updated: 2026-09-10. This milestone saves provider preferences; it does
not make cloud requests or claim tested Norwegian speech. Pricing, free quotas,
model availability, and account eligibility must be rechecked before activation.

| Route | Norwegian / English | Cost and authentication | Integration and tradeoff |
| --- | --- | --- | --- |
| XiaoZhi hosted service | Norwegian UI exists; that does not establish Norwegian STT/TTS quality. Record a bilingual voice trial. | Upstream advertises free personal Qwen usage with service registration; availability is external. | Native Opus/WebSocket or MQTT+UDP pipeline, vision/tools. Service-side configuration may not map to a generic API key/model field. |
| Gemini | TTS documentation lists Bokmål and Nynorsk; test accents, switching, STT, latency, and vision independently. | Some models have limited free tiers; API key required. Do not promise unlimited free voice. | Native Gemini API/Live differs from OpenAI-compatible APIs. Adapter needed; voice/style support is model-dependent. |
| OpenAI | TTS lists Norwegian, while voices are optimized for English. Measure speech recognition and spoken quality separately. | Usage-based API; key/billing independent of a consumer chat subscription. No free quota assumed. | Separate STT + LLM + TTS preserves canonical captions; streaming available. Use server-supported voices/speed; no arbitrary numerical pitch promise. |
| Self-hosted | NB-Whisper is Norwegian-oriented; also validate English using multilingual Whisper. Select and evaluate a separate Norwegian TTS voice. | No per-request vendor fee on your own hardware, but computer, electricity, and maintenance are needed. Optional gateway authentication. | Ollama supplies a model API, **not an entire STT/TTS voice pipeline**. Vision requires a suitable model. A reachable gateway composes speech and model services. |

Sources: [XiaoZhi README](https://github.com/78/xiaozhi-esp32),
[Gemini pricing](https://ai.google.dev/gemini-api/docs/pricing),
[Gemini Live capabilities](https://ai.google.dev/gemini-api/docs/live-api/capabilities),
[Gemini speech generation](https://ai.google.dev/gemini-api/docs/speech-generation),
[OpenAI speech generation](https://developers.openai.com/api/docs/guides/text-to-speech),
[OpenAI transcription](https://developers.openai.com/api/docs/guides/speech-to-text),
[NB-Whisper model card](https://huggingface.co/NbAiLab/nb-whisper-small),
[Ollama API](https://docs.ollama.com/api/introduction).

## Proposed first voice path

Reuse XiaoZhi's audio/wake-word/transport layer. The setup portal defaults to
XiaoZhi as the simplest first-run choice and does not ask for generic model,
URL, or API-key fields for that route. Start with push-to-talk and a gateway
that supports separate transcription, conversation, and synthesis.
This allows one canonical response to feed both captions and speech, independent
providers, and meaningful error reporting at each stage. XiaoZhi still needs to
pass the Norwegian acceptance trial before a release can promise bilingual
quality. A self-hosted gateway is the free-from-
per-call-charges option; travelling still requires a reachable gateway.

Cloud vision must be a separate intentional request/tool. Local preview never
needs an image upload. Raw idle audio stays on-device. Later audio transport
uses bounded frames/backpressure, verified TLS, cancellation, and service
timeouts. Neither API keys nor provider responses are put into debug logs.

## Acceptance trial before picking defaults

Use at least ten utterances in each language, including Norwegian dialects,
names, numbers, `æ/ø/å`, and language switches within a session. Include
"Hva er klokka?", "Vis meg hva du ser", and a visual question. Record:

- transcription errors and command routing;
- answer language and spoken naturalness (human judgement);
- time to first caption/audio and end-to-end latency;
- streaming interruptions, failure recovery, and caption agreement;
- actual provider usage/cost, privacy terms, and free-tier rejection behavior.

Do not store voice recordings unless the person testing explicitly agrees.
Pitch is only enabled when the chosen TTS adapter advertises it; changing the
playback sample rate is not a pitch-only control. Conversation model and speech
model are stored separately because the selected assistant model may not create
audio.

## Speech model, voice, and preview behavior

The embedded fallback catalogue follows the selected provider and speech model:

- XiaoZhi leaves both values service-managed. Its server can use several TTS
  implementations, so there is no truthful universal XiaoZhi voice list.
- Gemini lists the three currently documented TTS models and 30 named voices,
  including the provider's short voice characteristics.
- OpenAI defaults to `gpt-4o-mini-tts` with `marin`. Its `tts-1` and `tts-1-hd`
  choices reduce the dropdown to the smaller voice set documented for those
  models.
- Self-hosted leaves discovery to the future gateway adapter.

Conversation and speech services are independent settings. `Same as the
selected AI service` is the default, but a XiaoZhi conversation can be read by
Gemini TTS, OpenAI TTS, or a self-hosted gateway once the corresponding adapter
is connected. Provider keys are stored by provider, so one saved key is reused
when that provider handles both tasks; a different speech service can save a
separate key and endpoint without exposing either secret through the settings
API.

The portal states account and credential requirements before the user chooses a
service and links to XiaoZhi Console, Google AI Studio, or OpenAI Platform as
appropriate. These external pages need an internet connection and may not open
while a phone is still attached to BitBot's isolated setup hotspot.

The desktop simulator's Preview button uses the Web Speech API and labels the
result as a local browser sample. It verifies preview text, language, speed,
volume, and local pitch handling without sending credentials or pretending that
an installed system voice is Gemini, OpenAI, or XiaoZhi. The hardware portal
keeps the button disabled until an audio/provider adapter can generate and play
the exact selected voice. At that point the adapter must supply the live model
and voice catalogue and perform a short authenticated TTS request.

## Language catalogue behavior

The portal stores a BCP-47 language preference rather than a closed three-value
enum. `Automatic · Norwegian + English` remains the default, while
`Automatic · any supported language` and specific languages support an
international release. The visible list follows the selected route:

- XiaoZhi uses the upstream firmware locale list. This is a device-interface
  capability; final conversation and voice availability still depends on the
  XiaoZhi service configuration.
- Gemini uses the documented TTS catalogue for the separate speech model.
- OpenAI uses the documented TTS output-language catalogue because spoken
  output is the limiting part of the planned STT + LLM + TTS chain.
- Self-hosted shows the union of known language tags as candidates. Its future
  adapter must replace or confirm that list from the selected gateway.

The bundled catalogue is a commissioning fallback, not a permanent claim about
rapidly changing services. Provider adapters should report model, voice, and
language capabilities at runtime once those integrations exist. Unknown but
valid BCP-47 values remain loadable so third-party adapters can add languages
without migrating stored settings.

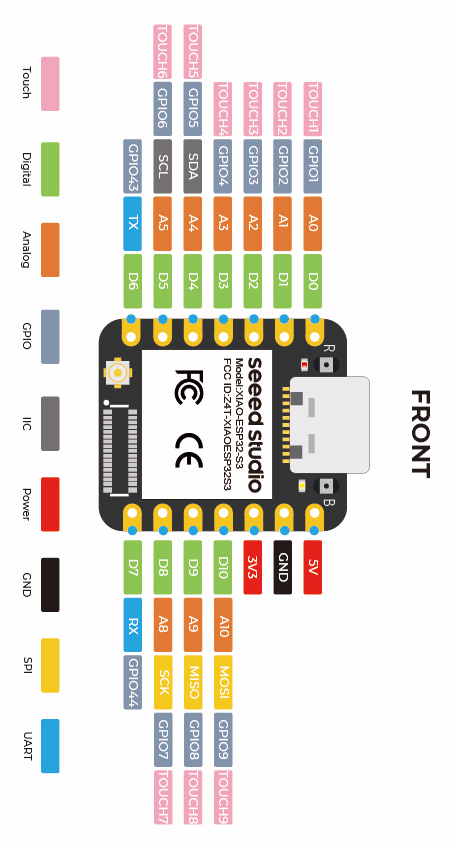
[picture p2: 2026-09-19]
esp32s3-pinout.png

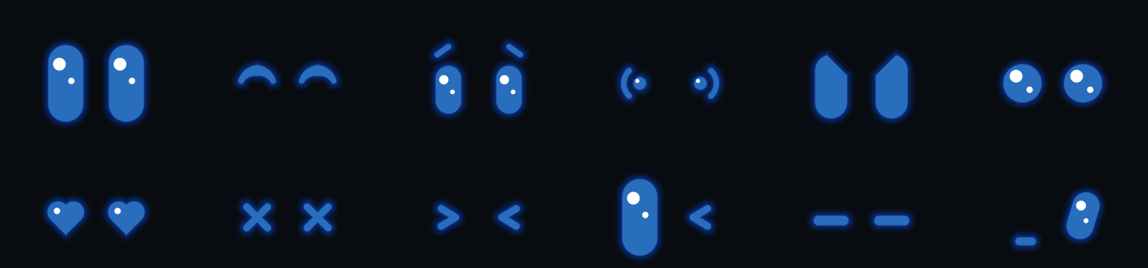
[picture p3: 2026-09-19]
docs/faces/all.png

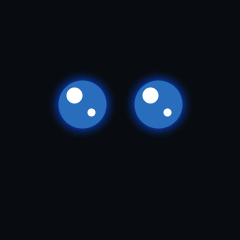
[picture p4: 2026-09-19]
docs/faces/06-cute.png

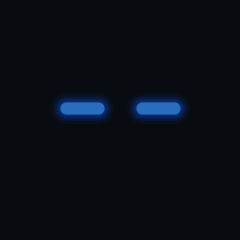
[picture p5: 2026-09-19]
docs/faces/11-exasperated.png

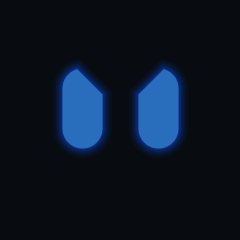
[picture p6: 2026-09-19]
docs/faces/05-angry.png

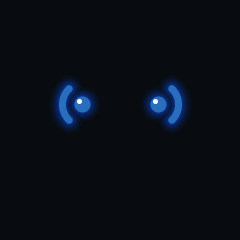
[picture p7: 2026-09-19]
docs/faces/04-scared.png

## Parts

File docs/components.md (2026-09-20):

# Component List — BitBot

Compiled from [BitBot_PROJECT_SPEC.md](../BitBot_PROJECT_SPEC.md) and
[hardware.md](hardware.md). Pins and electrical details are in hardware.md.
BitBot has no motors, servos or wheels.

| # | Component | Model / specification | Qty | Interface | Status |
| --- | --- | --- | --- | --- | --- |
| 1 | Microcontroller | Seeed Studio XIAO ESP32-S3 Sense (8 MB flash, 8 MB PSRAM, Wi-Fi, USB-C) | 1 | — | Confirmed |
| 2 | Camera | Included with XIAO Sense; this unit has an **OV3660** | 1 | DVP/SCCB | Verified on hardware 2026-09-19 |
| 3 | Built-in microphone | PDM microphone on the Sense board (GPIO 42/41) | 1 | PDM | Included, not planned for use |
| 4 | Display | 1.54" ST7789 TFT, 240×240, 8 pins (GND, VCC, SCL, SDA, RST, DC, CS, BL) | 1 | SPI | Verified on hardware 2026-09-19 |
| 5 | Microphone | INMP441 digital MEMS microphone, 1.8–3.3 V | 1 | I2S | Module pinout must be verified |
| 6 | Audio amplifier | MAX98357A I2S class D module, 2.5–5.5 V | 1 | I2S | Gain/SD connection must be verified |
| 7 | Speaker | Rectangular, approx. 15 × 11 × 3.5–4 mm | 1 | Differential output from MAX98357A | Impedance and power unknown |
| 8 | Battery | 1S Li-ion, protected. 10440 (approx. 350 mAh) is planned but likely too small for this module — see hardware.md | 1 | Module BAT+/BAT− | Cell choice under review |
| 9 | Charger/boost module | Type-C USB boost converter, 5 V 2 A step-up + 1S Li-ion charger/protection, 4-LED gauge. IC marked **FM5324GA** (IP5306 clone). Pads: USB-C in, BAT+, BAT−, 5V OUT+, OUT−, K (unusable), charge-voltage trim | 1 | 5 V rail | Purchased and identified; charge current and boost behaviour must be measured |
| 10 | Power switch | Self-locking on/off push button, 12 × 8 mm, rated 30 V / 1 A | 1 | In module 5V OUT+ line | Purchased |
| 11 | Setup button | Built-in BOOT button (GPIO0) | — | GPIO | Confirmed, part of XIAO |

## Not used

- The SD card reader on the Sense board (left empty; shares pins with the display SPI).
- Motors, motor drivers and servos.
- Battery voltage sensing (no divider on GPIO6). The module's 4-LED gauge is
  the only charge indicator.

## Open items

- Charger module: actual charge current into the cell, and whether the boost
  output starts by itself and stays on at BitBot's idle current. The K pad is
  labelled unusable on this board, so there is no button to restart the boost.
- The speaker's impedance and power rating.
- Which camera sensor is actually fitted.

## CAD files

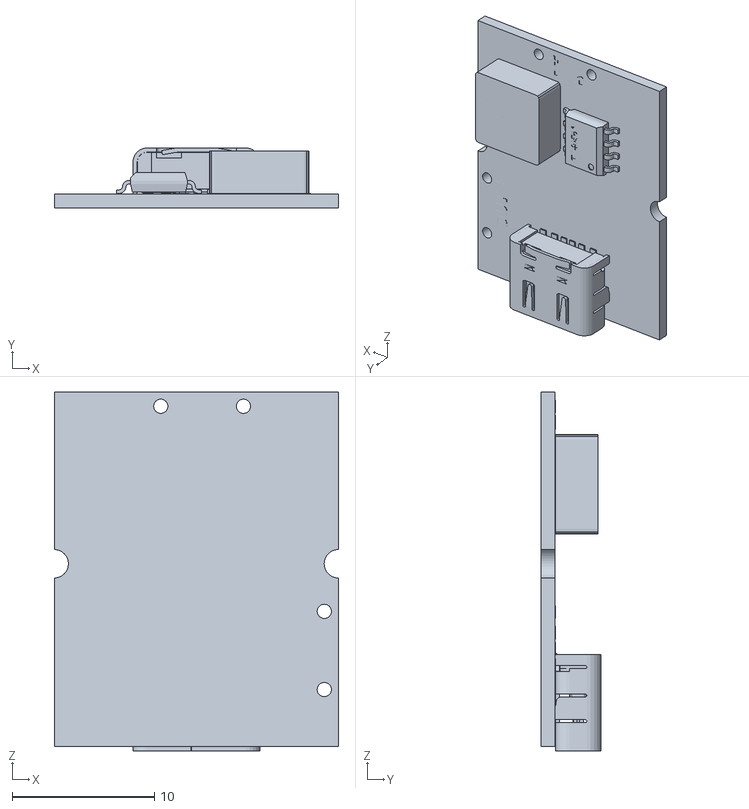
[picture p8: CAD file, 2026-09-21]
BitBot_3D-components/Type-C USB 5V 2A Boost Converter.STL
20.0 x 4.23 x 25.2

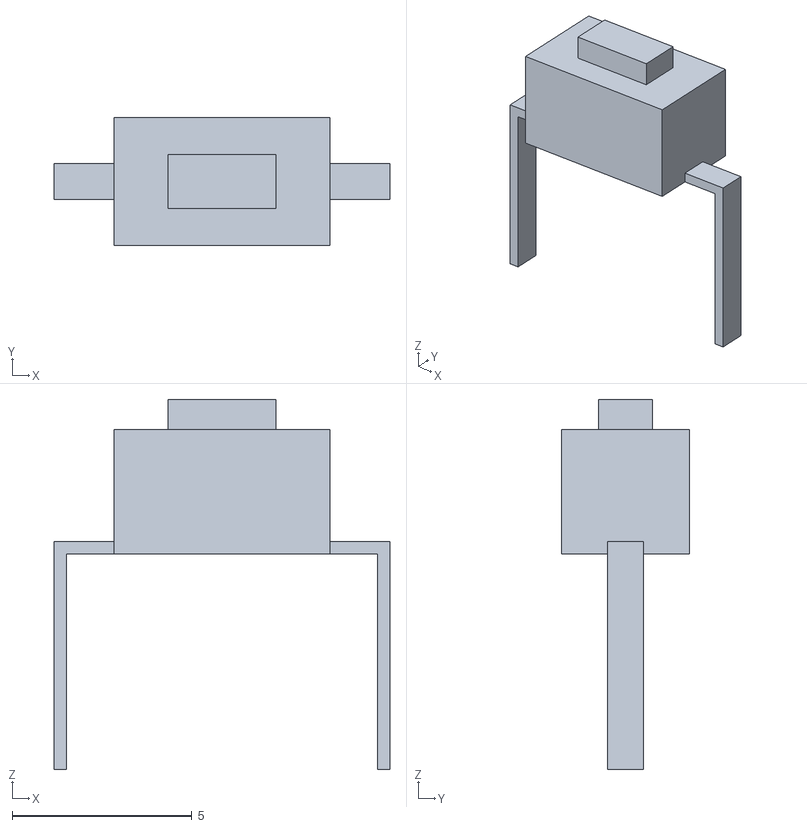
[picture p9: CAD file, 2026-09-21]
BitBot_3D-components/TS1101_3x6x4p3_THT_long_legs_6mm.stl
9.35 x 3.55 x 10.3

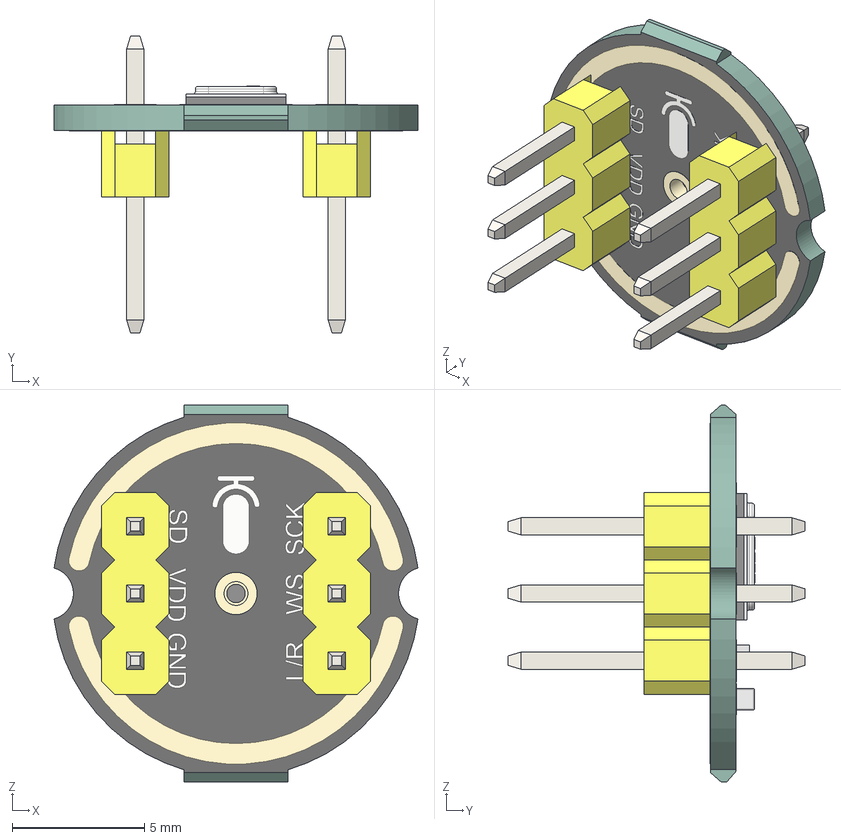
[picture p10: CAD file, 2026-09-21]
BitBot_3D-components/STEP/INMP441 I2S Microphone Module v15.step
13.8 x 11.2 x 14.2 mm
0603 Resistor

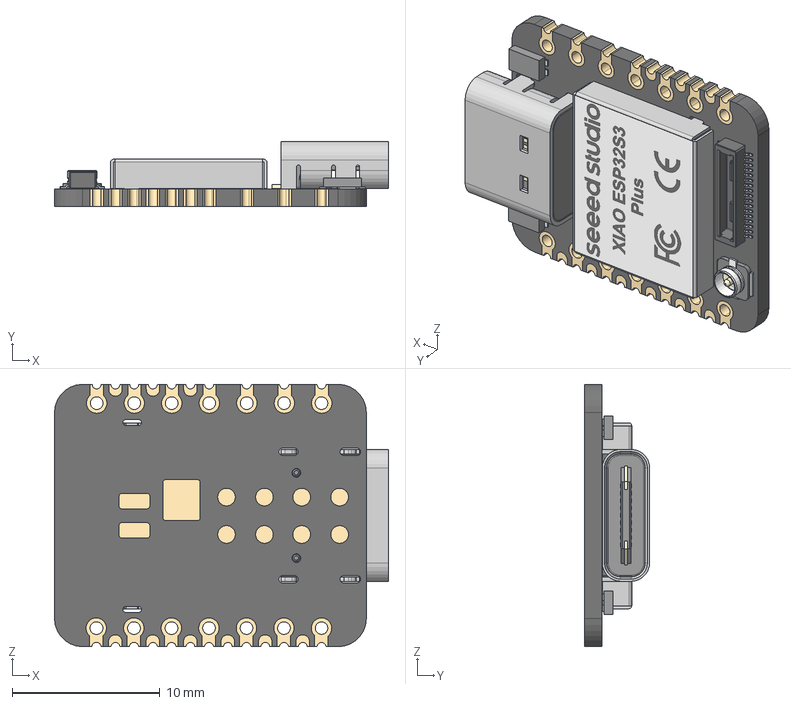
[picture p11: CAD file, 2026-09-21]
BitBot_3D-components/STEP/xiao-esp32s3-plus-v4.step
22.6 x 4.42 x 17.8 mm
DF40C-30DP-0.4V_51_ v1
BOSS-EXTRUDE14_8_
BOSS-EXTRUDE7_4_
BOSS-EXTRUDE7_3_
BOSS-EXTRUDE14_4_
BOSS-EXTRUDE14_2_
BOSS-EXTRUDE14_11_
BOSS-EXTRUDE7_7_
BOSS-EXTRUDE14_9_
BOSS-EXTRUDE14_3_
BOSS-EXTRUDE14_7_
MIRROR2
BOSS-EXTRUDE14_5_
BOSS-EXTRUDE14_12_
BOSS-EXTRUDE7_8_
BOSS-EXTRUDE7_1_
BOSS-EXTRUDE14_10_
BOSS-EXTRUDE7_9_
BOSS-EXTRUDE14_6_
BOSS-EXTRUDE14_1_
BOSS-EXTRUDE7_6_
BOSS-EXTRUDE7_2_
CUT-EXTRUDE5
BOSS-EXTRUDE7_5_
Shield
Pins x 2
U.FL-R-SMT-1_10_ v1

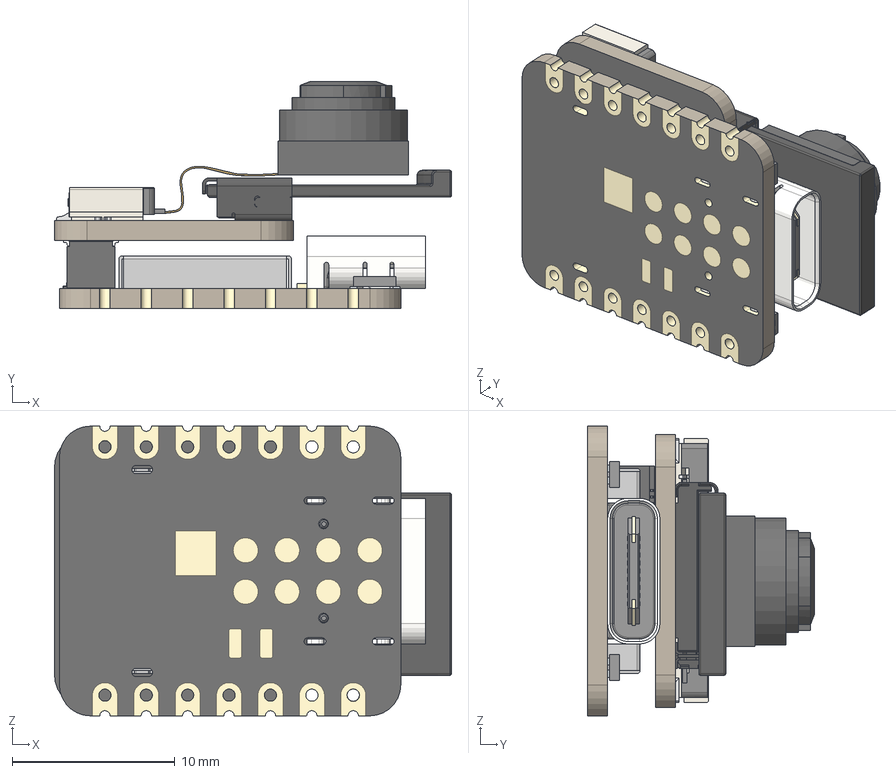
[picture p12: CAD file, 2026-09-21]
BitBot_3D-components/STEP/seeed-studio-xiao-esp32-s3-sense.step
24.4 x 14.0 x 17.8 mm
BOSS-EXTRUDE14_8_
BOSS-EXTRUDE7_4_
BOSS-EXTRUDE7_3_
BOSS-EXTRUDE14_4_
BOSS-EXTRUDE14_2_
BOSS-EXTRUDE14_11_
BOSS-EXTRUDE7_7_
BOSS-EXTRUDE14_9_
BOSS-EXTRUDE14_3_
BOSS-EXTRUDE14_7_
MIRROR2
BOSS-EXTRUDE14_5_
BOSS-EXTRUDE14_12_
BOSS-EXTRUDE7_8_
BOSS-EXTRUDE7_1_
BOSS-EXTRUDE14_10_
BOSS-EXTRUDE7_9_
BOSS-EXTRUDE14_6_
BOSS-EXTRUDE14_1_
BOSS-EXTRUDE7_6_
BOSS-EXTRUDE7_2_
CUT-EXTRUDE5
BOSS-EXTRUDE7_5_
Shield
Pins x 2
U.FL-R-SMT-1_10_ v1
DF40C-30DP-0.4V_51_ v1
DF40HC(3.0)-30DS
10067099-200LF v1
PCB
MicroSD v2
JUSHUO AFC01-S24FCA-00
Camer Module

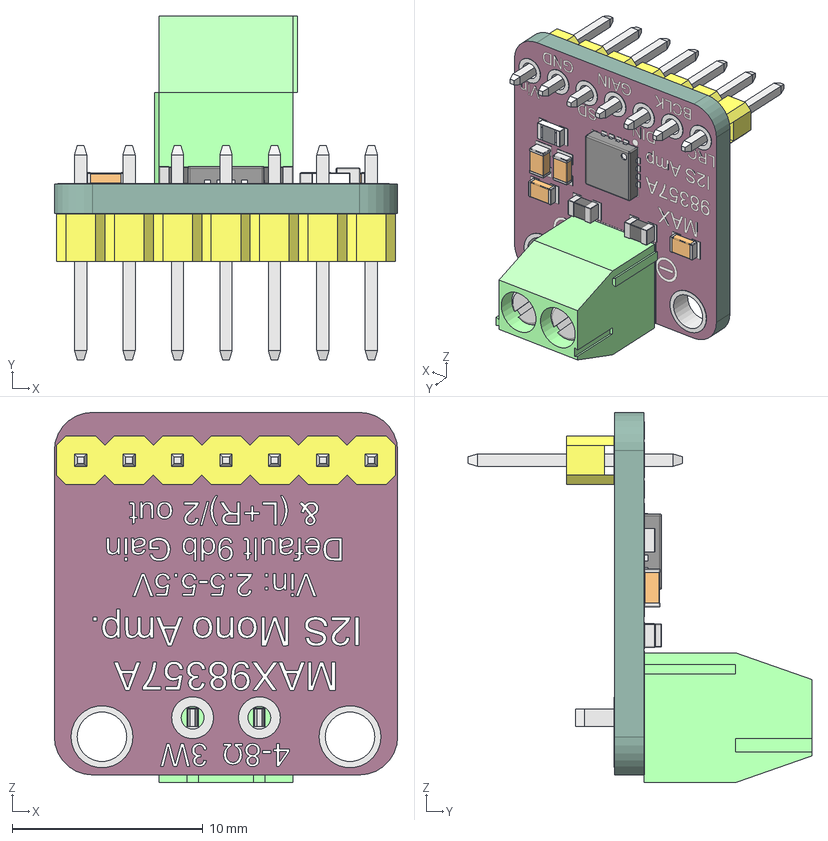
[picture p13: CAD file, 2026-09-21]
BitBot_3D-components/STEP/MAX98357A_3W_I2S_AMP v27.step
18.0 x 18.0 x 19.4 mm
PCB
M1.6x4-Screw030
0805 Ferrite x 2
Header

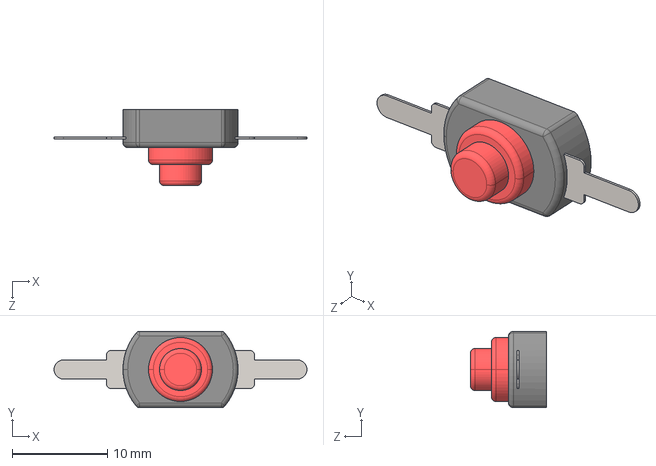
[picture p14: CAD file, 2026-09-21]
BitBot_3D-components/STEP/Push Button GrabCad.STEP
26.5 x 8.00 x 8.00 mm

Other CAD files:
BitBot_3D-components/INMP441 I2S Microphone Module v15.stl
BitBot_3D-components/MAX98357A_3W_I2S_AMP v27.stl
BitBot_3D-components/Push Button GrabCad.stl
BitBot_3D-components/seeed-studio-xiao-esp32-s3-sense.stl

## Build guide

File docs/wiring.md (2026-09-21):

# Wiring — soldering guide (prototype)

Derived from the pin allocation in [hardware.md](hardware.md). Nothing here is
verified on a built unit yet. Check every breakout's printed labels before
soldering; they vary between sellers.

## XIAO ESP32-S3 Sense header (top view, USB-C up)

```
                         ┌───────[USB-C]───────┐
 AMP DIN ── D0 / GPIO1  ●│                     │●  5V ← module 5V OUT+
 TFT RST ── D1 / GPIO2  ●│                     │●  GND
  SETUP ─── D2 / GPIO3  ●│   XIAO ESP32-S3     │●  3V3
  TFT CS ── D3 / GPIO4  ●│      Sense          │●  D10 / GPIO9  ── TFT SDA
 TFT DC ─── D4 / GPIO5  ●│                     │●  D9  / GPIO8  ── MIC SD
 I2S BCLK ─ D5 / GPIO6  ●│                     │●  D8  / GPIO7  ── TFT SCL
 (dead) ─── D6 / GPIO43 ●│                     │●  D7  / GPIO44 ── I2S WS
                         └─────────────────────┘
                           underside: BAT+  BAT-  (leave both unconnected)
```

**BCLK moved from D6/GPIO43 to D5/GPIO6.** GPIO43 cannot hold up as a fast I2S
clock (256 kHz - 1.4 MHz) on this board - confirmed by moving only the BCLK
wire to a spare pin and getting a clean signal on an otherwise unchanged
circuit (two different amp chips both misbehaved identically on GPIO43, which
rules out the amp). GPIO6 was free because battery sensing was never wired.

D6/GPIO43 is still usable for slow, occasional digital I/O: toggled at 1 Hz as
a plain GPIO output, it swings cleanly between 0 V and 3.3 V. It is the only
spare pin left on the D0-D10 header, so it is worth keeping for something like
a reset line or a button - just not for another fast clock or SPI/PWM bus,
which have not been tested and may hit the same limit.

D2/GPIO3 takes an optional setup button to GND (same as holding BOOT 3 s after
boot). GPIO3 is a strapping pin, but it only selects the JTAG source when the
STRAP_JTAG_SEL eFuse is burned, which it is not by default, so a button is safe.

## Full schematic

```
 ST7789 240×240, 8 pins         XIAO
 ┌─────┐
 │ GND ├──────────────────────── GND
 │ VCC ├──────────────────────── 3V3
 │ SCL ├──────────────────────── D8  / GPIO7   (SPI clock, not I2C)
 │ SDA ├──────────────────────── D10 / GPIO9   (SPI MOSI, not I2C)
 │ RST ├──────────────────────── D1  / GPIO2
 │ DC  ├──────────────────────── D4  / GPIO5
 │ CS  ├──────────────────────── D3  / GPIO4
 │ BL  ├──────────────────────── 3V3           (must not float)
 └─────┘

 INMP441 mic                     XIAO
 ┌─────┐
 │ VDD ├──────────────────────── 3V3
 │ GND ├──────────────────────── GND
 │ L/R ├──────────────────────── GND           (left slot)
 │ SCK ├──────────────────────── D5  / GPIO6   (I2S BCLK - moved off D6/GPIO43,
 │     │                              which is faulty on this board)
 │ WS  ├──────────────────────── D7  / GPIO44  (I2S WS)
 │ SD  ├──────────────────────── D9  / GPIO8   (mic data)
 └─────┘

 MAX98357A amp                   XIAO
 ┌──────┐
 │ BCLK ├──────────────────────── D5  / GPIO6   (same net as mic SCK; D6/GPIO43
 │      │                              is faulty on this board, moved off it)
 │ LRC  ├──────────────────────── D7  / GPIO44  (same net as mic WS)
 │ DIN  ├──────────────────────── D0  / GPIO1   (speaker data)
 │ GAIN ├── open                 (9 dB; floating is a real default per the datasheet)
 │ SD   ├──────────────────────── 3V3  (datasheet Table 5 has no floating state for
 │      │                              SD_MODE, only High/pullup/pullup/Low - leaving
 │      │                              it open drifts on breadboard noise from the
 │      │                              adjacent BCLK line. Tying to 3V3 = Left channel,
 │      │                              which sounds identical to L+R mix here since the
 │      │                              firmware duplicates the same sample into both.)
 │ GND  ├──────────────────────── GND
 │ VIN  ├──────────────────────── 5V rail after switch (see below)
 │ OUT+ ├──────── speaker +
 │ OUT- ├──────── speaker −      (neither side to GND!)
 └──────┘

 Power: FM5324GA / IP5306-clone module (USB-C in, 5 V 2 A boost out)

 ┌──────────┐
 │  USB-C   ├── BitBot's charging port (the only one used in normal operation)
 │  BAT +   ├──── cell +      the module owns the cell, nothing else does
 │  BAT −   ├──── cell −
 │   K      ├──── not connected (pad is labelled unusable on this board)
 │          │
 │  OUT +   ├──[ switch ]──┬──── XIAO 5V pad  (→ onboard 3V3 LDO)
 │          │              └──── MAX98357A VIN
 │          │
 │  OUT −   ├──────────────┬──── XIAO GND
 └──────────┘              └──── display GND, mic GND, amp GND
```

## Notes

- **One ground.** All GND points join: module OUT−/BAT−, XIAO GND, display,
  mic, amp.
- **The module is the only charger.** The XIAO's BAT+/BAT− pads stay empty.
  Two chargers on one cell is how cells vent. The cell goes to the module's
  BAT pads and nowhere else.
- **Switch sits in OUT+**, between the module and everything else. That keeps
  the spec's "charge while switched off" behaviour: USB-C charging works with
  the switch in either position.
- **Never plug the XIAO's USB-C in with the switch on.** The XIAO's 5V pad is
  VBUS with no blocking diode, so USB and the module's boost would fight.
  Switch off first, then flash. Rule of thumb: one USB-C at a time.
- **Amp on 5V, not 3V3 or the cell.** The MAX98357A takes 2.5–5.5 V, and the
  module supplies 2 A, so speaker peaks no longer sag the XIAO's regulator.
- **Boost auto-shutdown.** IP5306-family parts cut the 5 V output when the load
  draws under roughly 45–100 mA for about half a minute, and there is no usable
  K pad here to switch it back on. Measure this before relying on deep sleep;
  see the charging notes in [hardware.md](hardware.md).
- **No battery sensing.** BitBot does not measure the cell; the module's 4-LED
  gauge is the only charge indicator. D5/GPIO6 now carries I2S BCLK instead
  (moved there after GPIO43 was found faulty), so it is no longer free.
- **BL** to 3V3: on the fitted module a floating BL leaves the backlight off.
  Never drive it from a GPIO without knowing its current.
- **Shared I2S clocks**: BCLK and WS go to both mic and amp — solder a short
  jumper from the mic's pin to the amp's pin, then one wire to the XIAO.
- **BCLK is on D5/GPIO6, not D6/GPIO43.** GPIO43 is dead on this board (see
  above); nothing should be wired to D6.
- **SD card slot** must stay empty (it shares GPIO7/8/9).
- Keep I2S and SPI wires short (< 10 cm).

## Bring-up order

Solder and test one block at a time, powered from the XIAO's own USB-C with
the switch off and the module disconnected:
display → mic → amp + speaker.

Then, separately, bring up the power module on its own (cell + USB-C, no XIAO
attached): confirm charge current and termination, confirm the 5 V output under
a dummy load, and confirm what happens to that output at ~30 mA. Only after
that connect OUT+/OUT− to the XIAO, with the XIAO's USB-C unplugged.

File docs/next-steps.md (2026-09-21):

# Handoff and acceptance checklist

## Implemented

- English offline-capable portal, inspired by the paper/orange/dark visual
  language of the user's design reference. No copied assets or external fonts.
- Desktop simulator with durable local settings, explicit fake networking,
  connection failure simulation, mobile/desktop browser tests.
- ESP-IDF 6.0.2 commissioning target: USB console, BOOT hold, protected AP,
  bounded DNS responder, local HTTP API, session protection, NVS storage,
  five saved networks, test-before-save, reconnect/backoff, and finish/restart.
- Shared generated settings schema and compressed web assets; provider-specific
  key retention/removal. Preferences remain separate from Wi-Fi profiles.
- ST7789 240×240 driver for the fitted 8-pin module (CS on D3, SPI mode 3),
  verified on hardware. A small DMA stripe buffer, not a full framebuffer, and
  it waits for DMA completion before reusing a buffer. Face with twelve
  expressions, blinking and wandering eyes; text area with setup instructions,
  pairing code and captions; dimming in place of an unavailable backlight pin.
- XiaoZhi device activation: the OTA endpoint is asked for a pairing code, the
  code is shown on screen, and the device polls until the user adds it.
- Voice: full-duplex I2S (INMP441 + MAX98357A), Opus in and out, WebSocket to
  XiaoZhi, local wake phrases (esp-sr MultiNet), button push-to-talk, barge-in,
  captions, LLM emotions on the face, and MCP so XiaoZhi can ask for a photo.
- Camera: OV3660 identified on the Sense board; a photo is captured, shown on
  screen and uploaded to XiaoZhi's vision service only when the assistant asks.
- `hwtest/`: a separate bring-up program that reports each part on the screen.
  BOOT steps the speaker test tone through off / 2% / 10% / 40% / 40%-with-the-
  mic-off. Pressing BOOT within 3 s of reset instead enters the audio-only
  diagnostic: display, camera, battery and microphone all stay uninitialised and
  `app_main` does nothing but write a 440 Hz sine into I2S, so a tone that is
  still not clean there cannot be blamed on the rest of the firmware. Each
  further BOOT press steps to the next I2S format (16/32-bit, mono/stereo,
  16/44.1/48 kHz), which separates "the amplifier cannot lock onto this format"
  from "something is stalling the writer". `tools/tone_check.cpp` checks the
  waveform maths on a PC.
- Research and hardware documentation, including the confirmed display pin list.

## Next work, in order

1. **Physical commissioning test.** Flash via USB; join AP, test valid and wrong
   passwords, reboot, travel between two networks, forget one, and verify
   preferences/keys survive. Check AP closes, BOOT reopens it, and known-network
   connection recovers. Test from Android/iOS captive browsers and ordinary
   Chrome/Safari. Verify configuration is inaccessible from the joined LAN.
2. **Electrical verification.** Identify VCC/BL circuitry and speaker
   impedance/power. Bench-test the identified FM5324GA/IP5306-clone power
   module on its own — charge current into a cell, and whether its 5 V output
   survives a ~30 mA load — and pick the cell from that result. Keep
   battery/module wiring off the XIAO until then.
3. **Physical display test.** Enable the menuconfig option. Verify full 240×240
   area, RGB bars, inversion, row offset, and blink timing. Then add an original
   face renderer with setup instructions, WPA2 setup password, and readable
   Norwegian UTF-8 captions. Keep its API separate from conversation logic.
4. **Audio/camera independently.** Verify the proposed shared I2S clocks
   and matching sample formats. Record microphone PCM locally, test amplifier
   at low volume, and capture/release one camera frame.
5. **XiaoZhi integration.** Pin a tested upstream revision; keep BitBot board,
   face and commissioning code isolated. Migrate settings explicitly; do not
   silently overwrite upstream Wi-Fi namespaces or copy the AI Pin binary.
6. **Speaker output on real hardware.** The firmware decodes and writes ~1 s of
   audio per second to I2S during a reply (measured), but nothing has been heard
   yet. Check the MAX98357A supply (it needs the 5 V rail, which is dead when
   the module switch is off and only USB is connected), its SD pin, the shared
   ground, and the speaker across OUT+/OUT−.
7. **"Hey BitBot" as a real wake word.** esp-sr's English MultiNet only matches
   real English words, so today's phrases are "hey robot" / "hey bit robot".
   A trained WakeNet model for the actual phrase is the only way to get it;
   until then the button is the reliable path.
8. **Power.** Measure current in each state before enabling aggressive sleep or
   estimating battery life. The power module's low-load cutoff may put a floor
   under the sleep states. The battery divider on GPIO6 is still unwired; the
   test firmware reports it as floating.

## What automated checks establish

Node tests validate simulator persistence/rollback, input limits, API access
rules, secret redaction, and networking contract. Playwright covers the real
shared portal in Chromium desktop and mobile emulation, with no external
asset requests. ESP-IDF CI compiles and links the target firmware.

These checks do **not** prove physical Wi-Fi timing, AP/STA channel changes,
NVS behavior during power loss, GPIO wiring, actual LCD colors, audio quality,
battery safety/runtime, or real Norwegian/provider performance. Record those
results here when hardware is available; do not label them tested in advance.

## Known first-milestone limitations

- Saved AI/voice/display preferences are mostly contracts for later adapters.
  No AI calls, audio capture/playback, cloud vision, wake-word engine, captions,
  backlight dimming, or NTP/local tools yet. There is no battery sensing.
- The physical setup password is output to the USB console for bring-up; screen
  presentation and a polished no-computer first-boot experience are next.
- Endpoint validation does not prove an endpoint is compatible/reachable. The
  bundled speech model and voice lists are documented fallbacks; provider
  connection testing and live catalogue discovery do not exist yet.
- XiaoZhi account pairing is not integrated yet. Its authenticated console owns
  the live language-filtered voice list and provider audio samples. The portal
  links there and can store a separate speech-provider choice in the meantime.
- The hosted service options are candidates, not measured recommendations.
- Firmware and simulator have separate native storage/network implementations;
  shared schema and UI reduce drift but do not replace physical integration tests.
- AP/STA use one radio channel. Testing a network can briefly interrupt the
  browser's hotspot connection; the saved configuration survives reconnecting.
- The current partition layout intentionally has no OTA slots. Design assets,
  wake-word storage, OTA capacity and migration together before release.

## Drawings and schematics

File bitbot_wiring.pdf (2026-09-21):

# BitBot - wiring schematic

# By Torgeir Bull

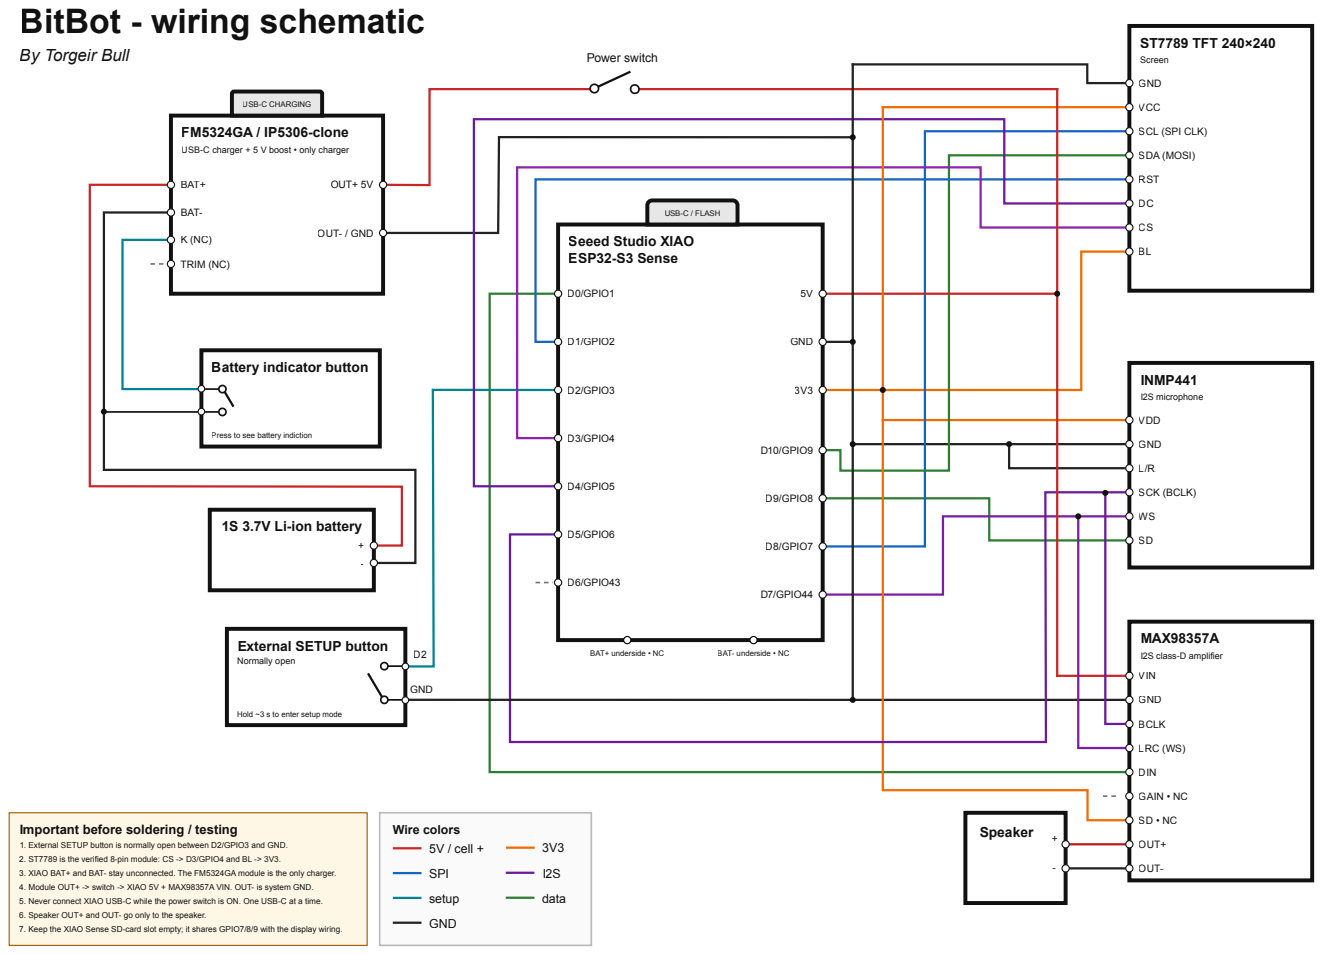
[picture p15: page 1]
Wire colors 5V / cell +; GND; SPI; setup; data; ST7789 TFT 240×240; Screen; INMP441; I2S microphone; MAX98357A; I2S class-D amplifier; Speaker; USB-C CHARGING; USB-C / FLASH; BAT+; BAT-; TRIM (NC); OUT+ 5V; OUT- / GND; Power switch; D0/GPIO1; D1/GPIO2; D2/GPIO3; D3/GPIO4; D4/GPIO5; D5/GPIO6; D6/GPIO43; D10/GPIO9; D9/GPIO8; D8/GPIO7; D7/GPIO44; BAT+ underside • NC; BAT- underside • NC; VCC; SCL (SPI CLK); SDA (MOSI); RST; VDD; SCK (BCLK); VIN; BCLK; LRC (WS); DIN; GAIN • NC; OUT+; OUT-

FM5324GA / IP5306-clone
USB-C charger + 5 V boost • only charger

Seeed Studio XIAO
ESP32-S3 Sense

Battery indicator button

Press to see battery indiction

1S 3.7V Li-ion battery

External SETUP button
Normally open

Hold ~3 s to enter setup mode

Important before soldering / testing
1. External SETUP button is normally open between D2/GPIO3 and GND.
2. ST7789 is the verified 8-pin module: CS -> D3/GPIO4 and BL -> 3V3.
3. XIAO BAT+ and BAT- stay unconnected. The FM5324GA module is the only charger.
4. Module OUT+ -> switch -> XIAO 5V + MAX98357A VIN. OUT- is system GND.
5. Never connect XIAO USB-C while the power switch is ON. One USB-C at a time.
6. Speaker OUT+ and OUT- go only to the speaker.
7. Keep the XIAO Sense SD-card slot empty; it shares GPIO7/8/9 with the display wiring.

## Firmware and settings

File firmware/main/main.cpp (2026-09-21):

#include "bitbot.h"
#include "display.h"
#include "voice.h"
#include "xiaozhi.h"
#include <driver/gpio.h>
#include <esp_log.h>
#include <esp_system.h>
#include <esp_heap_caps.h>
#include <freertos/FreeRTOS.h>
#include <freertos/task.h>

namespace bitbot {
// What the screen tells the user to do next, as rotating {small, big} pages.
static std::vector<Page> Guide(State state, const std::string& ssid, const std::string& password) {
    switch (state) {
        case State::Setup: return {{"1. Join Wi-Fi", ssid}, {"Password", password}, {"2. Follow setup", "on your phone"}};
        case State::Booting:
        case State::Connecting: return {{"Connecting to", "Wi-Fi ..."}};
        case State::Offline: return {{"No Wi-Fi found", "Retrying"}, {"New network? Hold", "BOOT 3 sec"}};
        case State::Error: return {{"Something failed", "See USB log"}};
        case State::Idle: break;
    }
    const auto xiaozhi = GetXiaozhiStatus();
    switch (xiaozhi.pairing) {
        case Pairing::Checking: return {{"Connecting to", "XiaoZhi ..."}};
        case Pairing::Code: return {{"1. Go to", "xiaozhi.me"}, {"2. Tap Console", "and sign in"}, {"3. Add a device", "with the code"}, {"Your code is", xiaozhi.code}};
        case Pairing::Paired: return {{"", "Say \"Hey Robot\""}};  // second line sits ~20 px lower
        case Pairing::Failed: return {{"Can't reach", "XiaoZhi"}, {"Retrying", "shortly"}};
        case Pairing::Off: break;
    }
    return {{"BitBot is", "online"}};
}
}

extern "C" void app_main() {
    using namespace bitbot;
    if (!LoadSettings()) {
        ESP_LOGE("bitbot", "Stored configuration could not be loaded. NVS was preserved; inspect over USB before recovery.");
        return;
    }
    gpio_config_t button = {};
    button.pin_bit_mask = 1ULL << kSetupButton | 1ULL << kExternalSetupButton;
    button.mode = GPIO_MODE_INPUT; button.pull_up_en = GPIO_PULLUP_ENABLE;
    ESP_ERROR_CHECK(gpio_config(&button));
    ESP_LOGI("bitbot", "Commissioning 0.1.0; free heap %u; free PSRAM %u", static_cast<unsigned>(esp_get_free_heap_size()), static_cast<unsigned>(heap_caps_get_free_size(MALLOC_CAP_SPIRAM)));
    InitNetwork();
    InitDisplay();
    StartXiaozhi();
    StartVoice();
    if (cJSON_GetArraySize(cJSON_GetObjectItemCaseSensitive(shared.document, "networks")) == 0) OpenSetup();
    else StartStation();
    int64_t pressed_at = 0;
    bool handled = false;
    // GPIO0 only reaches this code after a normal boot. Holding at reset enters ROM.
    while (true) {
        if (gpio_get_level(static_cast<gpio_num_t>(kSetupButton)) == 0 || gpio_get_level(static_cast<gpio_num_t>(kExternalSetupButton)) == 0) {
            if (!pressed_at) pressed_at = NowMs();
            if (!handled && NowMs() - pressed_at >= 3000) { OpenSetup(); handled = true; }
        } else {
            // Any press that did not reach the 3 s setup hold starts or ends a conversation.
            if (pressed_at && !handled && NowMs() - pressed_at >= 30) {
                ESP_LOGI("bitbot", "Button released after %d ms", static_cast<int>(NowMs() - pressed_at));
                PressVoiceButton();
            }
            pressed_at = 0; handled = false;
        }
        TickNetwork();
        State state; std::string ssid, password;
        { std::lock_guard<std::mutex> lock(shared.mutex); state = shared.state; ssid = shared.setup_ssid; password = shared.setup_password; }
        SetDisplayPages(Guide(state, ssid, password));
        // Sleep: while idle, waiting for "Hey Robot", the screen dims. A conversation wakes it.
        constexpr int64_t kDimAfterMs = CONFIG_BITBOT_DISPLAY_DIM_SECONDS * 1000LL;
        static int64_t awake_since = 0;
        if (VoiceActive() || state != State::Idle) awake_since = NowMs();
        SetDisplayDim(kDimAfterMs > 0 && NowMs() - awake_since > kDimAfterMs);
        TickDisplay(state);
        bool restart;
        { std::lock_guard<std::mutex> lock(shared.mutex); restart = shared.restart_at && NowMs() >= shared.restart_at; }
        if (restart) esp_restart();
        vTaskDelay(pdMS_TO_TICKS(10));
    }
}

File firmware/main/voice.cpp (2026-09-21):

#include "voice.h"
#include "audio.h"
#include "bitbot.h"
#include "camera.h"
#include "display.h"
#include "xiaozhi.h"
#include <algorithm>
#include <atomic>
#include <cmath>
#include <cstring>
#include <esp_crt_bundle.h>
#include <esp_log.h>
#include <esp_mn_iface.h>
#include <esp_mn_models.h>
#include <esp_mn_speech_commands.h>
#include <esp_opus_dec.h>
#include <esp_opus_enc.h>
#include <esp_websocket_client.h>
#include <freertos/FreeRTOS.h>
#include <freertos/event_groups.h>
#include <freertos/queue.h>
#include <freertos/task.h>
#include <model_path.h>
#include <memory>
#include <mutex>
#include <vector>

// Protocol: 78/xiaozhi-esp32 docs/websocket.md, binary protocol version 1 (raw Opus frames).
namespace bitbot {
static constexpr const char* kTag = "bitbot_voice";
static constexpr int kFrameMs = 60, kFrameSamples = kAudioRate * kFrameMs / 1000;  // Opus frame, both ways
// Wake phrases for the English MultiNet (mn7_en), given as esp-sr phonemes (its own alphabet, see
// model/multinet_model/fst/commands_en.txt and tool/multinet_g2p.py).
//
// Measured on this board by feeding recorded clips straight into the recogniser: it only matches
// phrases built from real English words. "hey robot" (p=0.33) and "hey bit robot" (p=0.26) are
// recognised; "hey bitbot", "hey bit bot" and even "hey bot" never are, however clearly spoken.
// A true "hey bitbot" needs a WakeNet model trained on that phrase; see docs/next-steps.md.
// ponytail: the button always works, so treat these as a convenience, not the only way in.
static const struct { const char* text; const char* phonemes; } kWakePhrases[] = {
    {"hey bit robot", "hd BgT RbBnT"},  // closest to "BitBot" that the model can hear
    {"hey robot", "hd RbBnT"},
    {"okay robot", "bKd RbBnT"},
    {"hi robot", "hi RbBnT"},
};
// esp_websocket_client aborts the whole connection when a write times out, so this is the longest
// Wi-Fi stall a conversation survives, not a per-frame deadline. Blocking here drops some mic DMA;
// losing a little audio beats losing the call.
static constexpr int kSendTimeoutMs = 3000;
static constexpr int kReplyTimeoutMs = 8000;  // silence from the server while "speaking" means it is over
static constexpr float kWakeThreshold = 0.2f;  // ponytail: esp-sr default; lower made detection worse, not better

enum class Voice { Off, Idle, Connecting, Listening, Speaking };
static std::atomic<Voice> voice{Voice::Off};
static std::atomic<bool> wake_heard{false}, button_pressed{false}, tts_done{false}, sleep_requested{false};
static std::atomic<int> pending_audio{0};
static std::atomic<int64_t> last_activity{0}, last_received{0};  // last sign of life from the server
static std::atomic<int> sent_frames{0}, received_frames{0}, mic_peak{0}, played_samples{0}, decode_errors{0}, underruns{0};  // for the once-a-second log line

static std::mutex ws_mutex;  // guards ws and session_id between the voice, mic and WebSocket tasks
static esp_websocket_client_handle_t ws = nullptr;
static std::string session_id;
static std::string vision_url, vision_token;  // from the MCP handshake; token is a secret
static EventGroupHandle_t ws_events;
static constexpr EventBits_t kWsConnected = 1, kWsHello = 2, kWsClosed = 4;
struct Packet { uint8_t* data; size_t size; };
static QueueHandle_t playback;  // Opus packets from the server, freed by the speaker task

struct Prefs { int volume = 20, idle_s = 30; bool captions = true; };  // matches config/settings-schema.json
static Prefs ReadPrefs() {
    std::lock_guard<std::mutex> lock(shared.mutex);
    const auto* s = cJSON_GetObjectItemCaseSensitive(shared.document, "settings");
    Prefs p;
    if (const auto* v = cJSON_GetObjectItemCaseSensitive(s, "volume"); cJSON_IsNumber(v)) p.volume = v->valueint;
    if (const auto* v = cJSON_GetObjectItemCaseSensitive(s, "idleSeconds"); cJSON_IsNumber(v)) p.idle_s = std::max(10, v->valueint);
    if (const auto* v = cJSON_GetObjectItemCaseSensitive(s, "captions"); cJSON_IsBool(v)) p.captions = cJSON_IsTrue(v);
    return p;
}
static Prefs prefs;

// XiaoZhi's LLM emotions onto the face's expressions.
static Expression FromEmotion(const std::string& e) {
    if (e == "happy" || e == "cool" || e == "confident" || e == "relaxed") return Expression::Happy;
    if (e == "laughing" || e == "funny") return Expression::Laughing;
    if (e == "loving" || e == "kissy") return Expression::Love;
    if (e == "surprised" || e == "shocked") return Expression::Surprised;
    if (e == "angry") return Expression::Angry;
    if (e == "sad" || e == "crying") return Expression::PutOff;
    if (e == "embarrassed" || e == "delicious") return Expression::Cute;
    if (e == "winking" || e == "silly") return Expression::Winking;
    if (e == "thinking" || e == "confused") return Expression::Sceptical;
    if (e == "sleepy") return Expression::Exasperated;
    return Expression::Neutral;
}
static void Caption(const std::string& text, bool is_caption = true) {
    if (is_caption && !prefs.captions) { SetDisplayCaption(" "); return; }  // blank, not the idle guide
    SetDisplayCaption(text);
}

// Everything we send goes out through one task. Sending Opus straight from the microphone task took
// the client's internal lock every 60 ms, which starved the control messages and the receive path
// ("Could not lock ws-client" in the log), so the server never saw "listen" and never answered.
struct Outgoing { std::string* payload; bool binary; };
static QueueHandle_t outbox;

static bool Enqueue(std::string&& payload, bool binary) {
    { std::lock_guard<std::mutex> lock(ws_mutex); if (!ws) return false; }
    Outgoing message{new std::string(std::move(payload)), binary};
    if (xQueueSend(outbox, &message, 0) == pdTRUE) return true;
    delete message.payload;  // a full queue drops one audio frame rather than stalling the microphone
    return false;
}
static bool SendText(const std::string& text) { return Enqueue(std::string(text), false); }
static void SenderTask(void*) {
    for (;;) {
        Outgoing message;
        if (xQueueReceive(outbox, &message, portMAX_DELAY) != pdTRUE) continue;
        std::unique_ptr<std::string> payload(message.payload);
        esp_websocket_client_handle_t client;
        { std::lock_guard<std::mutex> lock(ws_mutex); client = ws; }
        if (!client) continue;
        if (message.binary) {
            if (esp_websocket_client_send_bin(client, payload->data(), payload->size(), pdMS_TO_TICKS(kSendTimeoutMs)) > 0) ++sent_frames;
        } else {
            esp_websocket_client_send_text(client, payload->data(), payload->size(), pdMS_TO_TICKS(kSendTimeoutMs));
        }
    }
}
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

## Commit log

2026-09-10 Add initial HTML structure and CSS styles for BitBot setup interface
    [partitions.csv]
2026-09-10 Turn setup portal into a guided flow
2026-09-17 Add initial documentation for components and wiring
2026-09-17 replaced schematics-image
2026-09-17 Enhance documentation for power module specifications and wiring details
2026-09-19 Add XiaoZhi voice interaction and hardware test functionality
    - Implement voice interaction with XiaoZhi, allowing local wake phrases and button presses to initiate conversations.
    - Create new files for voice handling (`voice.h`, `xiaozhi.cpp`, `xiaozhi.h`) to manage the voice interaction logic and WebSocket communication.
    - Introduce a hardware test application (`hwtest`) to verify the functionality of various components, including display, microphone, speaker, battery, and camera.
    - Add necessary configurations and dependencies for the hardware test in `CMakeLists.txt` and `idf_component.yml`.
    - Implement display rendering for hardware test results, including audio feedback and battery vol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
    [partitions.csv]
2026-09-19 Add wiring schematic for BitBot in SVG format
2026-09-20 Add camera functionality and integrate with vision service
    - Implement camera initialization and capture functionality in camera.cpp and camera.h.
    - Add a method to upload captured images to a vision service and retrieve responses.
    - Update display functionality to show captured images on the screen.
    - Modify voice recognition to include new wake phrases and adjust pairing instructions.
    - Refactor face rendering logic to accommodate new display dimensions and ensure proper rendering.
    - Adjust network settings to optimize performance and reduce latency during audio streaming.
    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
2026-09-21 Refactor audio handling and diagnostics in BitBot firmware
    - Added a new tone generation system for speaker tests, including a dedicated tone.h file.
    - Implemented audio-only diagnostic mode to test speaker functionality without other components.
    - Enhanced audio task management to ensure smooth operation of microphone and speaker tasks.
    - Introduced a queue system for sending audio data to prevent blocking and improve responsiveness.
    - Improved logging for audio operations, including write statistics and error handling.
    - Updated display handling to reflect audio states and diagnostics.
    - Added functionality to check for audio signal integrity and ensure proper tone generation.
    [audio.cpp, display.cpp, main.cpp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]
2026-09-21 Fix I2S BCLK pin assignment and update documentation
    - Moved I2S BCLK from D6/GPIO43 to D5/GPIO6 due to GPIO43's inability to handle fast I2S clock signals.
    - Updated hardware and wiring documentation to reflect the new pin assignments and clarify GPIO43's status as a slow GPIO.
    - Adjusted audio initialization code to use the correct BCLK pin.
    - Removed battery sensing code as GPIO6 is now used for BCLK, leaving no spare ADC pin.
    - Added a test task for GPIO43 to verify its functionality as a slow digital output.
    [audio.cpp, main.cpp]
2026-09-21 Enhance camera tool descriptions for clarity and usability
2026-09-21 Add STL file for Seeed Studio XIAO ESP32-S3 Sense component
    [INMP441 I2S Microphone Module v15.step, INMP441 I2S Microphone Module v15.stl, MAX98357A_3W_I2S_AMP v27.step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]
